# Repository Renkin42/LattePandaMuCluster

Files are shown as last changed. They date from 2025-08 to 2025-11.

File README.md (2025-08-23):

Latte Panda Mu Cluster Board
============================

This is a Mini-DTX cluster board for five Latte Panda Mu system-on-modules. Each slot recieves two sata connections, an m.2 M-key slot at pcie gen3x2 and a 2.5gb ethernet 
connection via an RTL8125B. Slot 1 has two USB-3 connections broken out to the rear IO along with HDMI and a single USB Type C port on a front panel header. Slots 2 and 3 
Each have a Front USB-3 connection, a rear USB-3 connection, and an M.2 E-key slot. Slots 4 and 5 have an open-back pcie gen 3x4 slot.

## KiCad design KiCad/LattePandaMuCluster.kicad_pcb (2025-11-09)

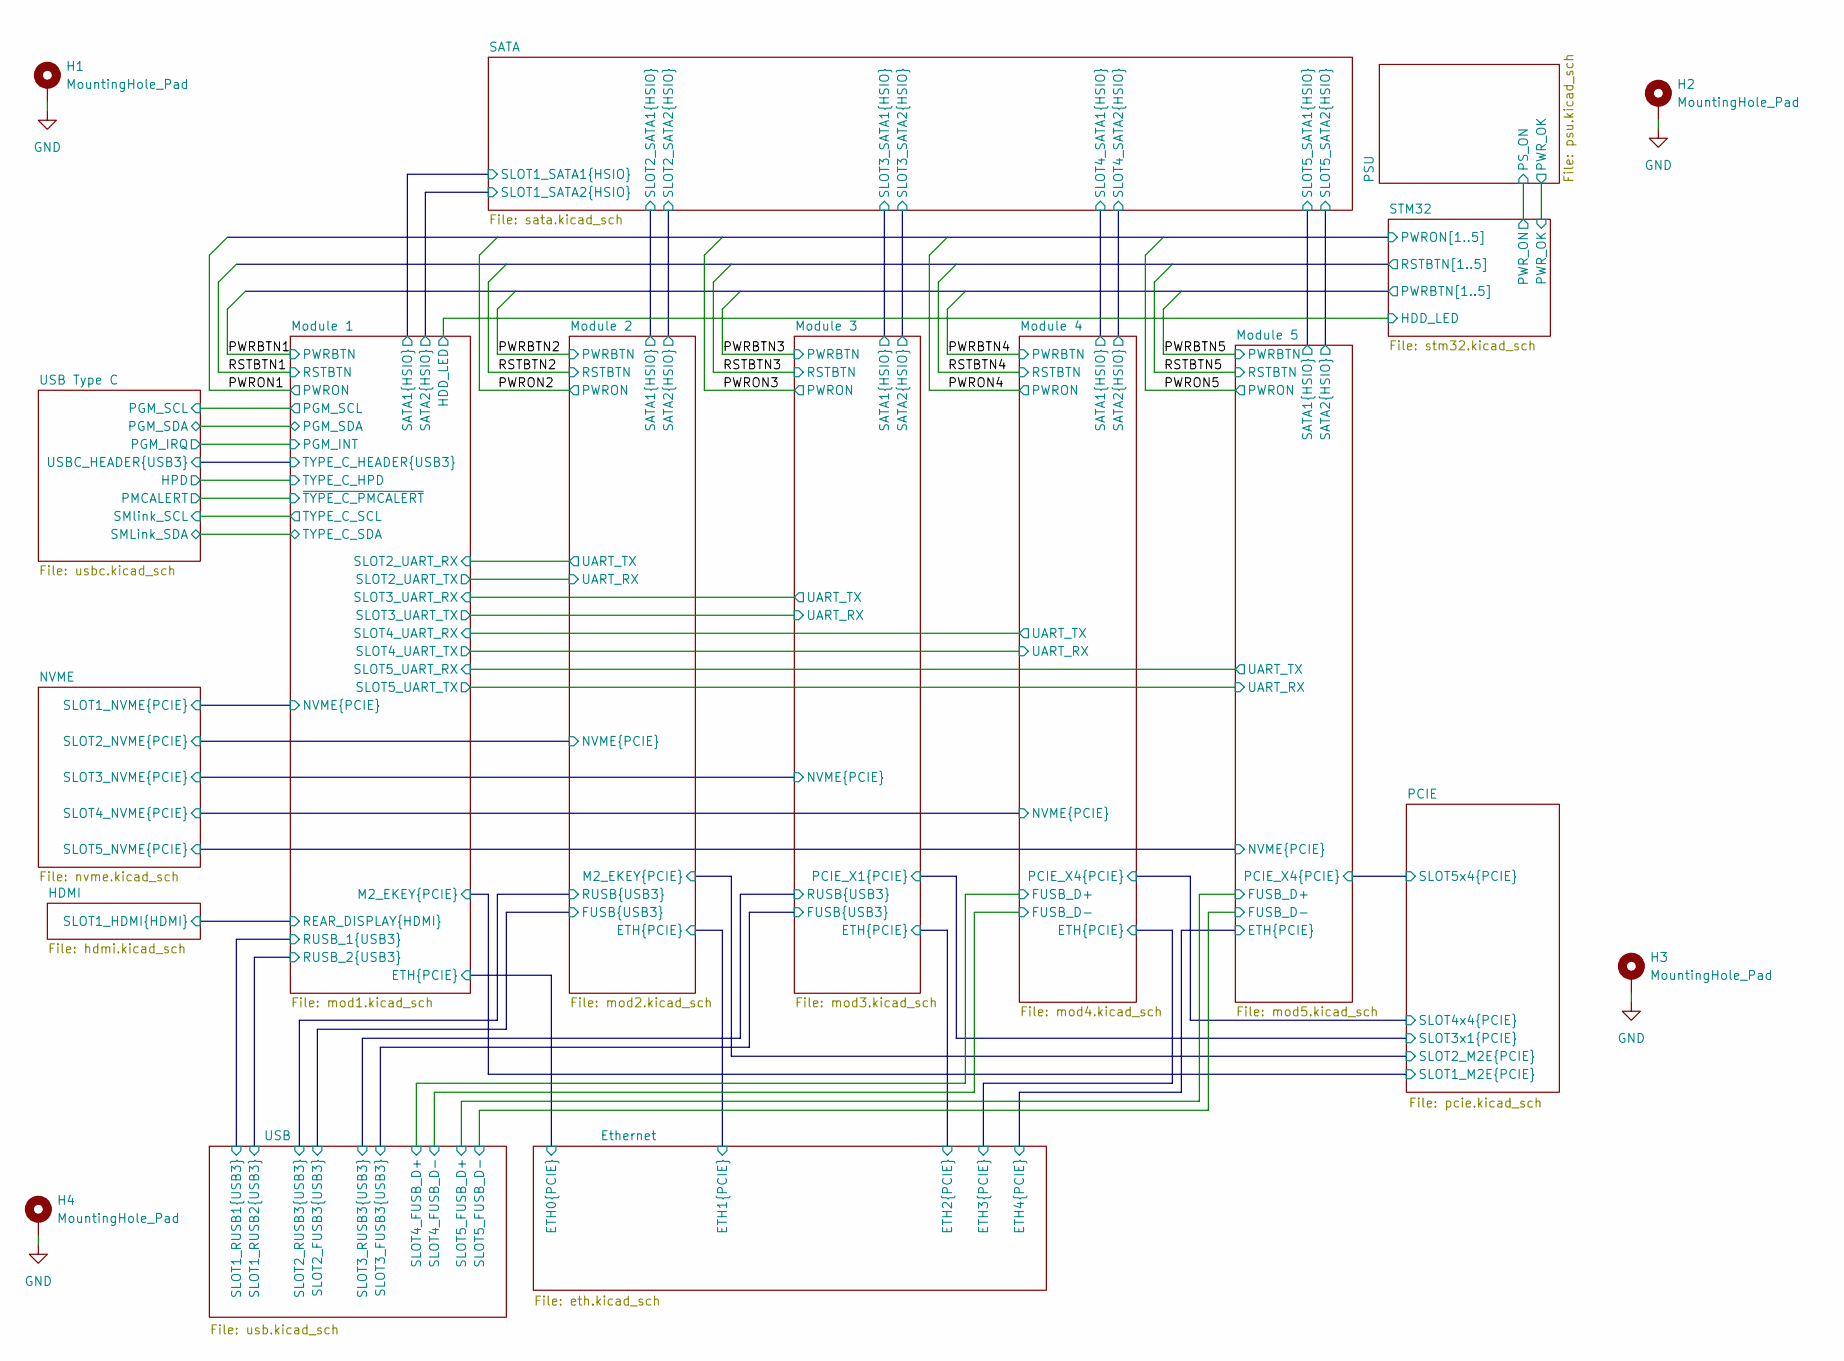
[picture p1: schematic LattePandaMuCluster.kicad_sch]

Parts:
H1, H2, H3, H4: MountingHole_Pad; MountingHole_4mm_Pad_Via

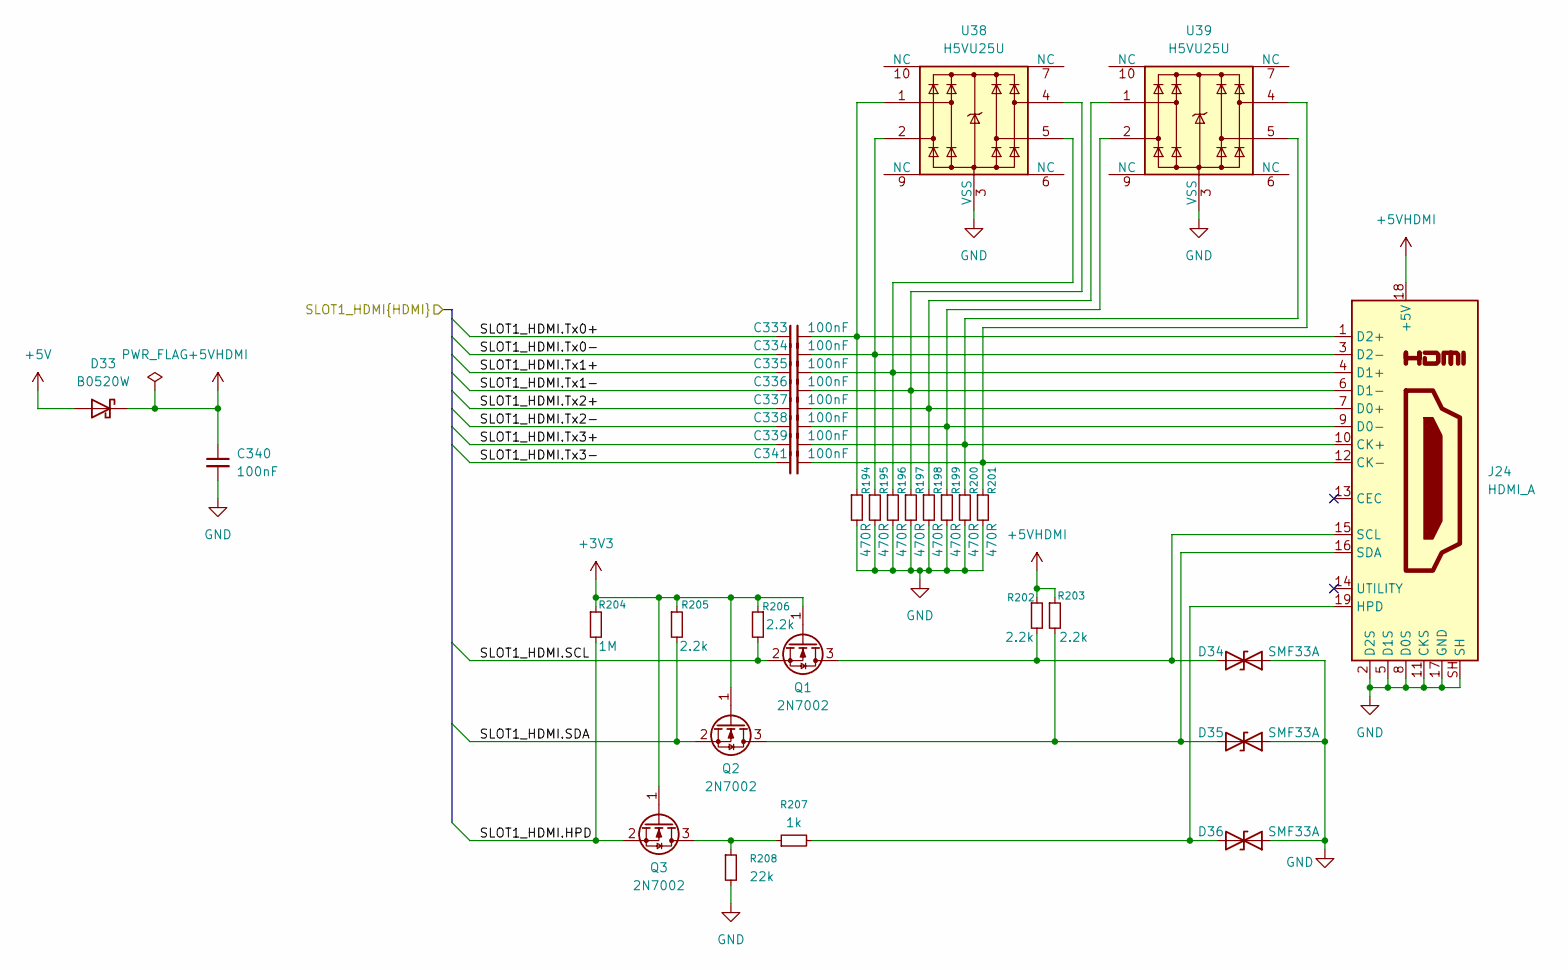
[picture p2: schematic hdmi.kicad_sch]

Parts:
C333, C334, C335, C336, C337, C338, C339, C340, C341: 100nF; C_0402_1005Metric
D33: B0520W; D_SOD-123
D34, D35, D36: SMF33A; D_SOD-123F
J24: HDMI_A; HDMI_A_Molex_208658-1001_Horizontal
Q1, Q2, Q3: 2N7002; SOT-23
R194, R195, R196, R197, R198, R199, R200, R201: 470R; R_0402_1005Metric
R202, R203, R205, R206: 2.2k; R_0402_1005Metric
R204: 1M; R_0402_1005Metric
R207: 1k; R_0805_2012Metric
R208: 22k; R_0402_1005Metric
U38, U39: H5VU25U; Diodes_UDFN-10_1.0x2.5mm_P0.5mm

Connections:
+3V3: Q1.1 (G), Q2.1 (G), Q3.1 (G), R204.1, R205.1, R206.1; also elsewhere on the board
+5V: D33.2 (A); also elsewhere on the board
+5VHDMI: C340.1, D33.1 (K), J24.18 (+5V), R202.1, R203.1
/HDMI/SLOT1_HDMI.HPD: Q3.2 (S), R204.2; also elsewhere on the board
/HDMI/SLOT1_HDMI.SCL: Q1.2 (S), R206.2; also elsewhere on the board
/HDMI/SLOT1_HDMI.SDA: Q2.2 (S), R205.2; also elsewhere on the board
/HDMI/SLOT1_HDMI.Tx0+: C333.1; also elsewhere on the board
/HDMI/SLOT1_HDMI.Tx0-: C334.1; also elsewhere on the board
/HDMI/SLOT1_HDMI.Tx1+: C335.1; also elsewhere on the board
/HDMI/SLOT1_HDMI.Tx1-: C336.1; also elsewhere on the board
/HDMI/SLOT1_HDMI.Tx2+: C337.1; also elsewhere on the board
/HDMI/SLOT1_HDMI.Tx2-: C338.1; also elsewhere on the board
/HDMI/SLOT1_HDMI.Tx3+: C339.1; also elsewhere on the board
/HDMI/SLOT1_HDMI.Tx3-: C341.1; also elsewhere on the board
unnamed: D34.2 (A2), J24.15 (SCL), Q1.3 (D), R202.2
unnamed: D35.2 (A2), J24.16 (SDA), Q2.3 (D), R203.2
unnamed: D36.2 (A2), J24.19 (HPD), R207.2
unnamed: C339.2, J24.10 (CK+), R200.1, U39.5
unnamed: C341.2, J24.12 (CK-), R201.1, U39.4
unnamed: C337.2, J24.7 (D0+), R198.1, U39.1
unnamed: C338.2, J24.9 (D0-), R199.1, U39.2
unnamed: C335.2, J24.4 (D1+), R196.1, U38.5
unnamed: C336.2, J24.6 (D1-), R197.1, U38.4
unnamed: C333.2, J24.1 (D2+), R194.1, U38.1
unnamed: C334.2, J24.3 (D2-), R195.1, U38.2
unnamed: Q3.3 (D), R207.1, R208.1

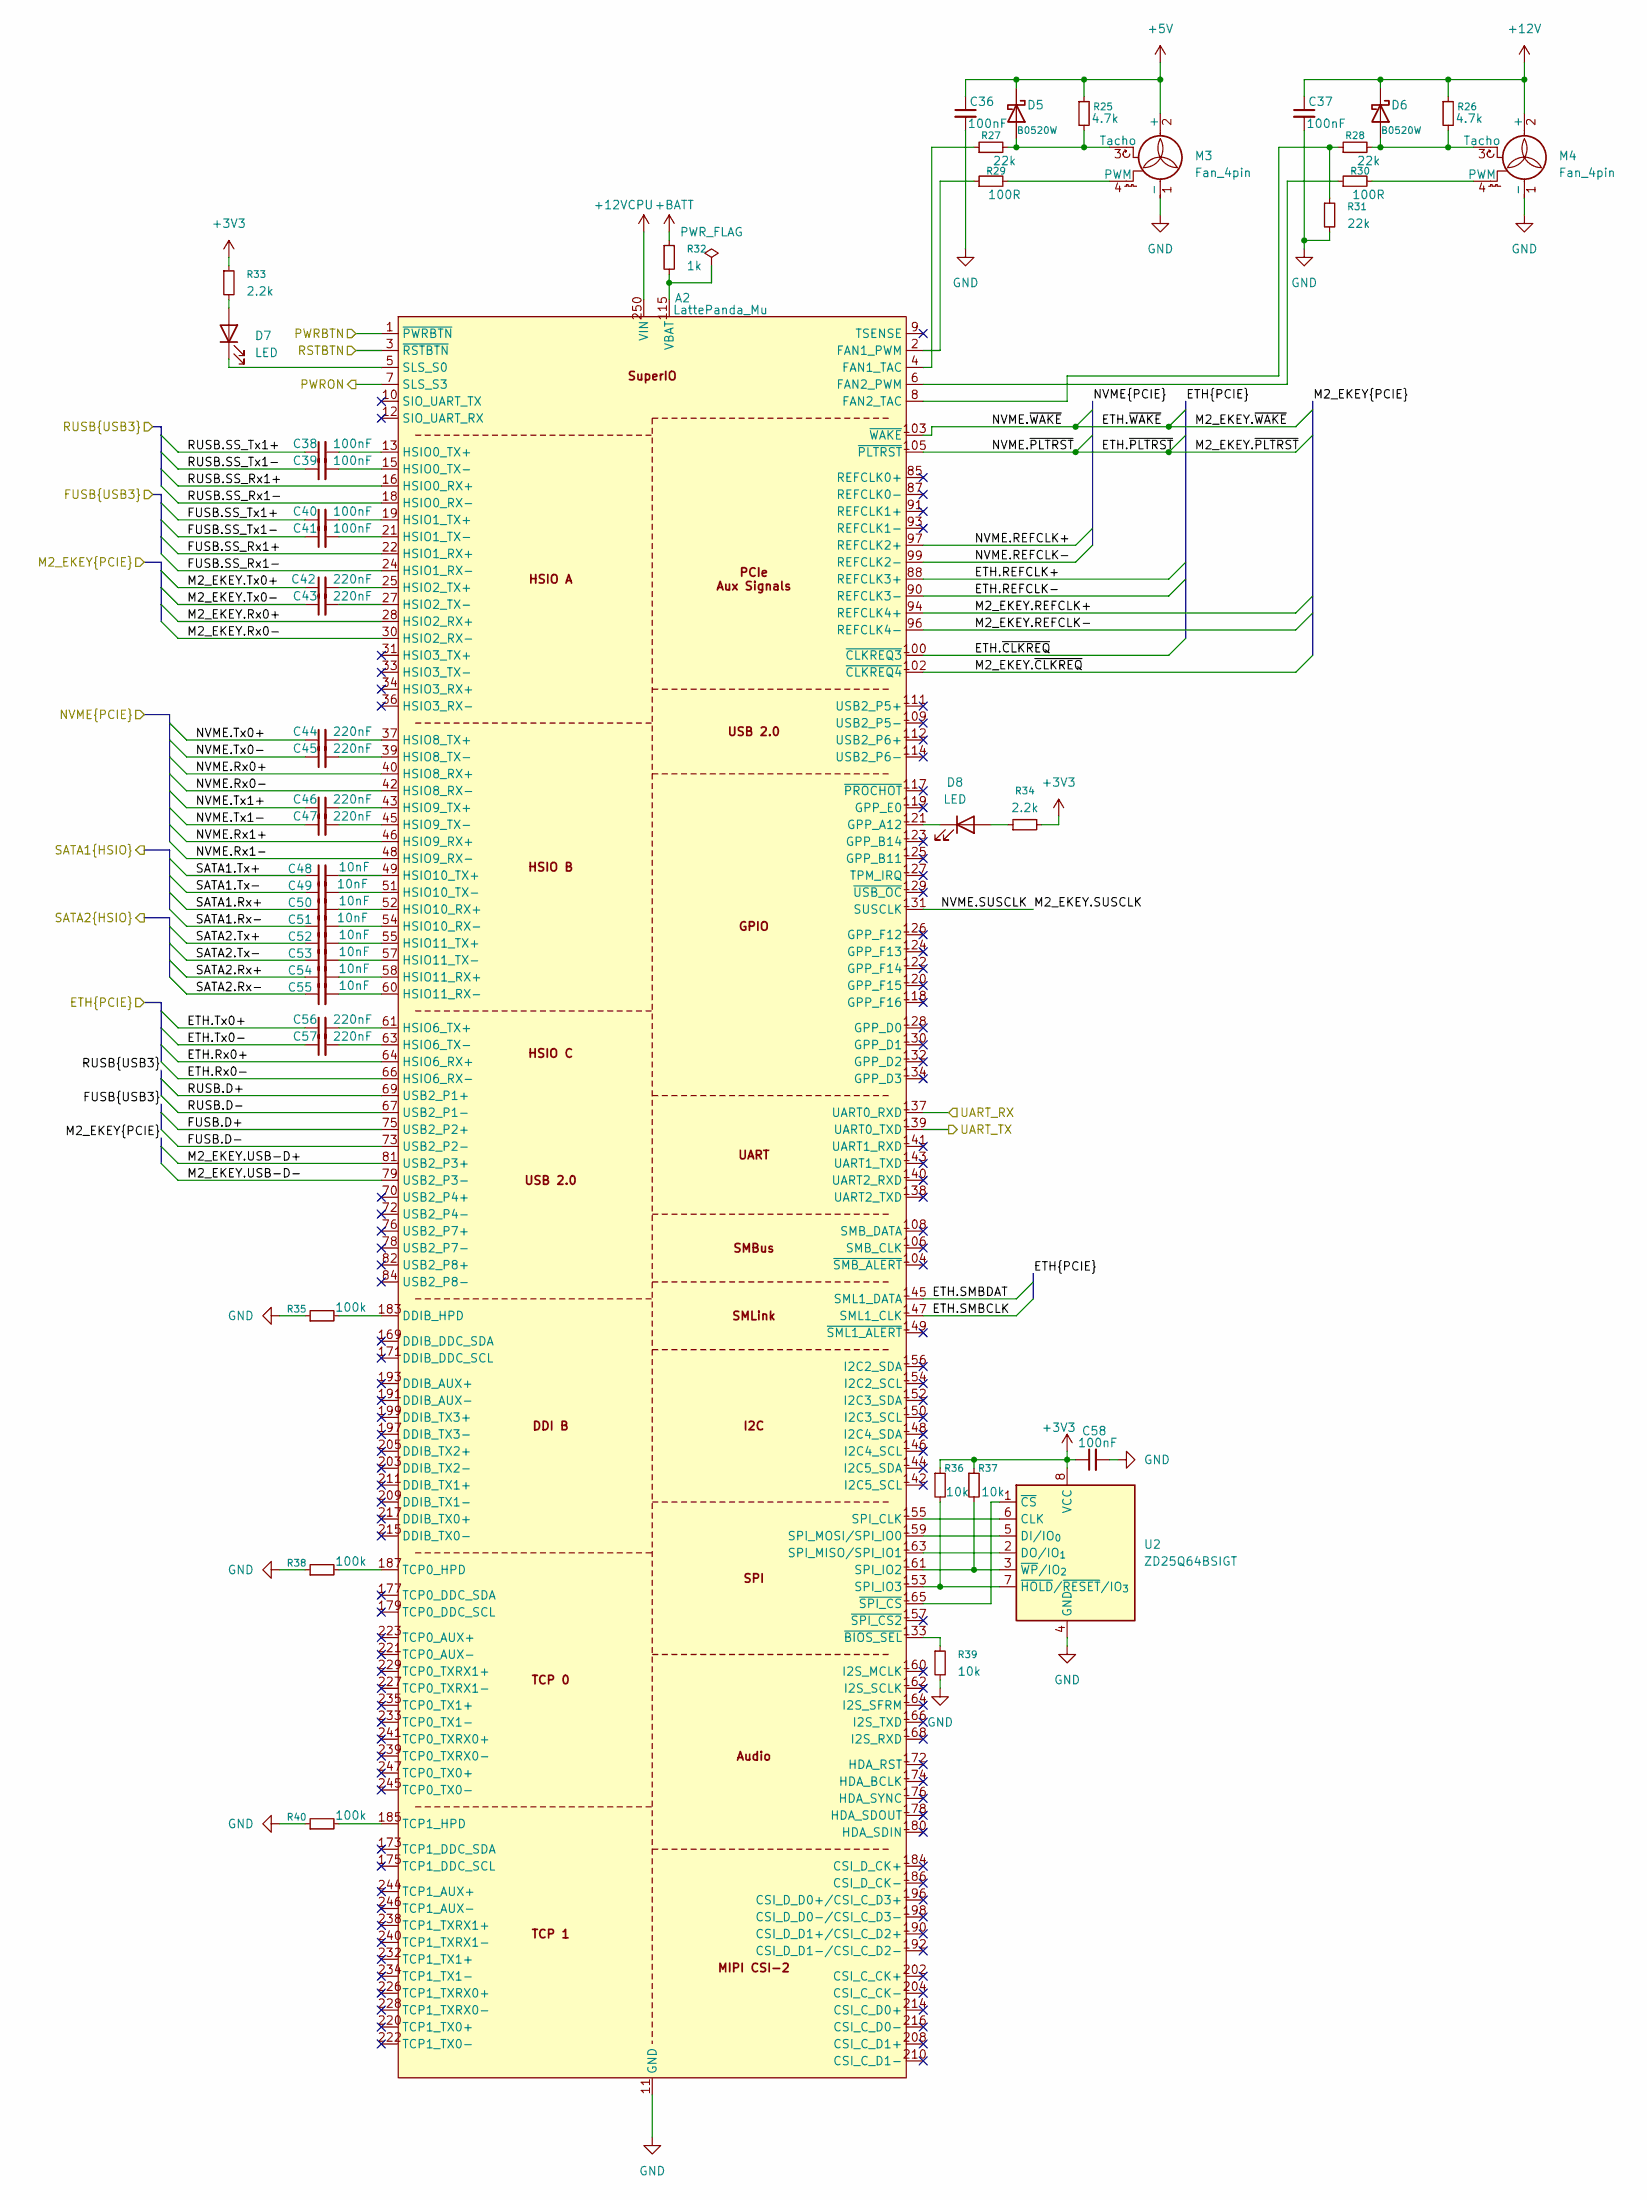
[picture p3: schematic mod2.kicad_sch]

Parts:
A2: LattePanda_Mu; ATTEND_124B-150A02
C36, C37, C38, C39, C40, C41, C58: 100nF; C_0402_1005Metric
C42, C43, C44, C45, C46, C47, C56, C57: 220nF; C_0402_1005Metric
C48, C49, C50, C51, C52, C53, C54, C55: 10nF; C_0402_1005Metric
D5, D6: B0520W; D_SOD-123
D7, D8: LED; LED_0603_1608Metric
M3: Fan_4pin; JST_PH_B4B-PH-K_1x04_P2.00mm_Vertical
M4: Fan_4pin; FanPinHeader_1x04_P2.54mm_Vertical
R25, R26: 4.7k; R_0402_1005Metric
R27, R28, R31: 22k; R_0402_1005Metric
R29, R30: 100R; R_0402_1005Metric
R32: 1k; R_0805_2012Metric
R33, R34: 2.2k; R_0402_1005Metric
R35, R38, R40: 100k; R_0402_1005Metric
R36, R37, R39: 10k; R_0402_1005Metric
U2: ZD25Q64BSIGT; SOIC-8_5.3x5.3mm_P1.27mm

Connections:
+3V3: C58.1, R33.1, R34.2, R36.1, R37.1, U2.8 (VCC); also elsewhere on the board
+5V: C36.1, D5.1 (K), M3.2 (+), R25.1; also elsewhere on the board
+12V: C37.1, D6.1 (K), M4.2 (+), R26.1; also elsewhere on the board
+12VCPU: A2.250 (VIN), A2.251 (VIN), A2.252 (VIN), A2.253 (VIN), A2.254 (VIN), A2.255 (VIN), A2.256 (VIN), A2.257 (VIN), A2.258 (VIN), A2.259 (VIN), A2.260 (VIN); also elsewhere on the board
+BATT: R32.1; also elsewhere on the board
/Module 1/SLOT2_UART_RX: A2.139 (UART0_TXD); also elsewhere on the board
/Module 1/SLOT2_UART_TX: A2.137 (UART0_RXD); also elsewhere on the board
/Module 2/ETH.REFCLK+: A2.88 (REFCLK3+); also elsewhere on the board
/Module 2/ETH.REFCLK-: A2.90 (REFCLK3-); also elsewhere on the board
/Module 2/ETH.Rx0+: A2.64 (HSIO6_RX+); also elsewhere on the board
/Module 2/ETH.Rx0-: A2.66 (HSIO6_RX-); also elsewhere on the board
/Module 2/ETH.SMBCLK: A2.147 (SML1_CLK); also elsewhere on the board
/Module 2/ETH.SMBDAT: A2.145 (SML1_DATA); also elsewhere on the board
/Module 2/ETH.Tx0+: C56.1; also elsewhere on the board
/Module 2/ETH.Tx0-: C57.1; also elsewhere on the board
/Module 2/ETH.~CLKREQ: A2.100 (~CLKREQ3); also elsewhere on the board
/Module 2/FUSB.D+: A2.75 (USB2_P2+); also elsewhere on the board
/Module 2/FUSB.D-: A2.73 (USB2_P2-); also elsewhere on the board
/Module 2/FUSB.SS_Rx1+: A2.22 (HSIO1_RX+); also elsewhere on the board
/Module 2/FUSB.SS_Rx1-: A2.24 (HSIO1_RX-); also elsewhere on the board
/Module 2/FUSB.SS_Tx1+: C40.1; also elsewhere on the board
/Module 2/FUSB.SS_Tx1-: C41.1; also elsewhere on the board
/Module 2/M2_EKEY.REFCLK+: A2.94 (REFCLK4+); also elsewhere on the board
/Module 2/M2_EKEY.REFCLK-: A2.96 (REFCLK4-); also elsewhere on the board
/Module 2/M2_EKEY.Rx0+: A2.28 (HSIO2_RX+); also elsewhere on the board
/Module 2/M2_EKEY.Rx0-: A2.30 (HSIO2_RX-); also elsewhere on the board
/Module 2/M2_EKEY.Tx0+: C42.1; also elsewhere on the board
/Module 2/M2_EKEY.Tx0-: C43.1; also elsewhere on the board
/Module 2/M2_EKEY.USB-D+: A2.81 (USB2_P3+); also elsewhere on the board
/Module 2/M2_EKEY.USB-D-: A2.79 (USB2_P3-); also elsewhere on the board
/Module 2/M2_EKEY.~CLKREQ: A2.102 (~CLKREQ4)
/Module 2/NVME.REFCLK+: A2.97 (REFCLK2+); also elsewhere on the board
/Module 2/NVME.REFCLK-: A2.99 (REFCLK2-); also elsewhere on the board
/Module 2/NVME.Rx0+: A2.40 (HSIO8_RX+); also elsewhere on the board
/Module 2/NVME.Rx0-: A2.42 (HSIO8_RX-); also elsewhere on the board
/Module 2/NVME.Rx1+: A2.46 (HSIO9_RX+); also elsewhere on the board
/Module 2/NVME.Rx1-: A2.48 (HSIO9_RX-); also elsewhere on the board
/Module 2/NVME.SUSCLK: A2.131 (SUSCLK); also elsewhere on the board
/Module 2/NVME.Tx0+: C44.1; also elsewhere on the board
/Module 2/NVME.Tx0-: C45.1; also elsewhere on the board
/Module 2/NVME.Tx1+: C46.1; also elsewhere on the board
/Module 2/NVME.Tx1-: C47.1; also elsewhere on the board
/Module 2/NVME.~PLTRST: A2.105 (~PLTRST); also elsewhere on the board
/Module 2/NVME.~WAKE: A2.103 (~WAKE); also elsewhere on the board
/Module 2/RUSB.D+: A2.69 (USB2_P1+); also elsewhere on the board
/Module 2/RUSB.D-: A2.67 (USB2_P1-); also elsewhere on the board
/Module 2/RUSB.SS_Rx1+: A2.16 (HSIO0_RX+); also elsewhere on the board
/Module 2/RUSB.SS_Rx1-: A2.18 (HSIO0_RX-); also elsewhere on the board
/Module 2/RUSB.SS_Tx1+: C38.1; also elsewhere on the board
/Module 2/RUSB.SS_Tx1-: C39.1; also elsewhere on the board
/Module 2/SATA1.Rx+: C50.1; also elsewhere on the board
/Module 2/SATA1.Rx-: C51.1; also elsewhere on the board
/Module 2/SATA1.Tx+: C48.1; also elsewhere on the board
/Module 2/SATA1.Tx-: C49.1; also elsewhere on the board
/Module 2/SATA2.Rx+: C54.1; also elsewhere on the board
/Module 2/SATA2.Rx-: C55.1; also elsewhere on the board
/Module 2/SATA2.Tx+: C52.1; also elsewhere on the board
/Module 2/SATA2.Tx-: C53.1; also elsewhere on the board
/STM32/PWRBTN2: A2.1 (~PWRBTN); also elsewhere on the board
/STM32/PWRON2: A2.7 (SLS_S3); also elsewhere on the board
/STM32/RSTBTN2: A2.3 (~RSTBTN); also elsewhere on the board
unnamed: A2.183 (DDIB_HPD), R35.2
unnamed: A2.2 (FAN1_PWM), R29.1
unnamed: A2.4 (FAN1_TAC), R27.1
unnamed: A2.6 (FAN2_PWM), R30.1
unnamed: A2.8 (FAN2_TAC), R28.1, R31.1
unnamed: A2.121 (GPP_A12), D8.1 (K)
unnamed: A2.13 (HSIO0_TX+), C38.2
unnamed: A2.15 (HSIO0_TX-), C39.2
unnamed: A2.19 (HSIO1_TX+), C40.2
unnamed: A2.21 (HSIO1_TX-), C41.2
unnamed: A2.25 (HSIO2_TX+), C42.2
unnamed: A2.27 (HSIO2_TX-), C43.2
unnamed: A2.61 (HSIO6_TX+), C56.2
unnamed: A2.63 (HSIO6_TX-), C57.2
unnamed: A2.37 (HSIO8_TX+), C44.2
unnamed: A2.39 (HSIO8_TX-), C45.2
unnamed: A2.43 (HSIO9_TX+), C46.2
unnamed: A2.45 (HSIO9_TX-), C47.2
unnamed: A2.52 (HSIO10_RX+), C50.2
unnamed: A2.54 (HSIO10_RX-), C51.2
unnamed: A2.49 (HSIO10_TX+), C48.2
unnamed: A2.51 (HSIO10_TX-), C49.2
unnamed: A2.58 (HSIO11_RX+), C54.2
unnamed: A2.60 (HSIO11_RX-), C55.2
unnamed: A2.55 (HSIO11_TX+), C52.2
unnamed: A2.57 (HSIO11_TX-), C53.2
unnamed: A2.5 (SLS_S0), D7.1 (K)
unnamed: A2.155 (SPI_CLK), U2.6 (CLK)
unnamed: A2.161 (SPI_IO2), R37.2, U2.3 (~WP/IO_{2})
unnamed: A2.153 (SPI_IO3), R36.2, U2.7 (~HOLD/~RESET/IO_{3})
unnamed: A2.163 (SPI_MISO/SPI_IO1), U2.2 (DO/IO_{1})
unnamed: A2.159 (SPI_MOSI/SPI_IO0), U2.5 (DI/IO_{0})
unnamed: A2.187 (TCP0_HPD), R38.2
unnamed: A2.185 (TCP1_HPD), R40.2
unnamed: A2.115 (VBAT), R32.2
unnamed: A2.133 (~BIOS_SEL), R39.1
unnamed: A2.165 (~SPI_CS), U2.1 (~CS)
unnamed: D5.2 (A), M3.3 (Tacho), R25.2, R27.2
unnamed: D6.2 (A), M4.3 (Tacho), R26.2, R28.2
unnamed: D7.2 (A), R33.2
unnamed: D8.2 (A), R34.1
unnamed: M3.4 (PWM), R29.2
unnamed: M4.4 (PWM), R30.2

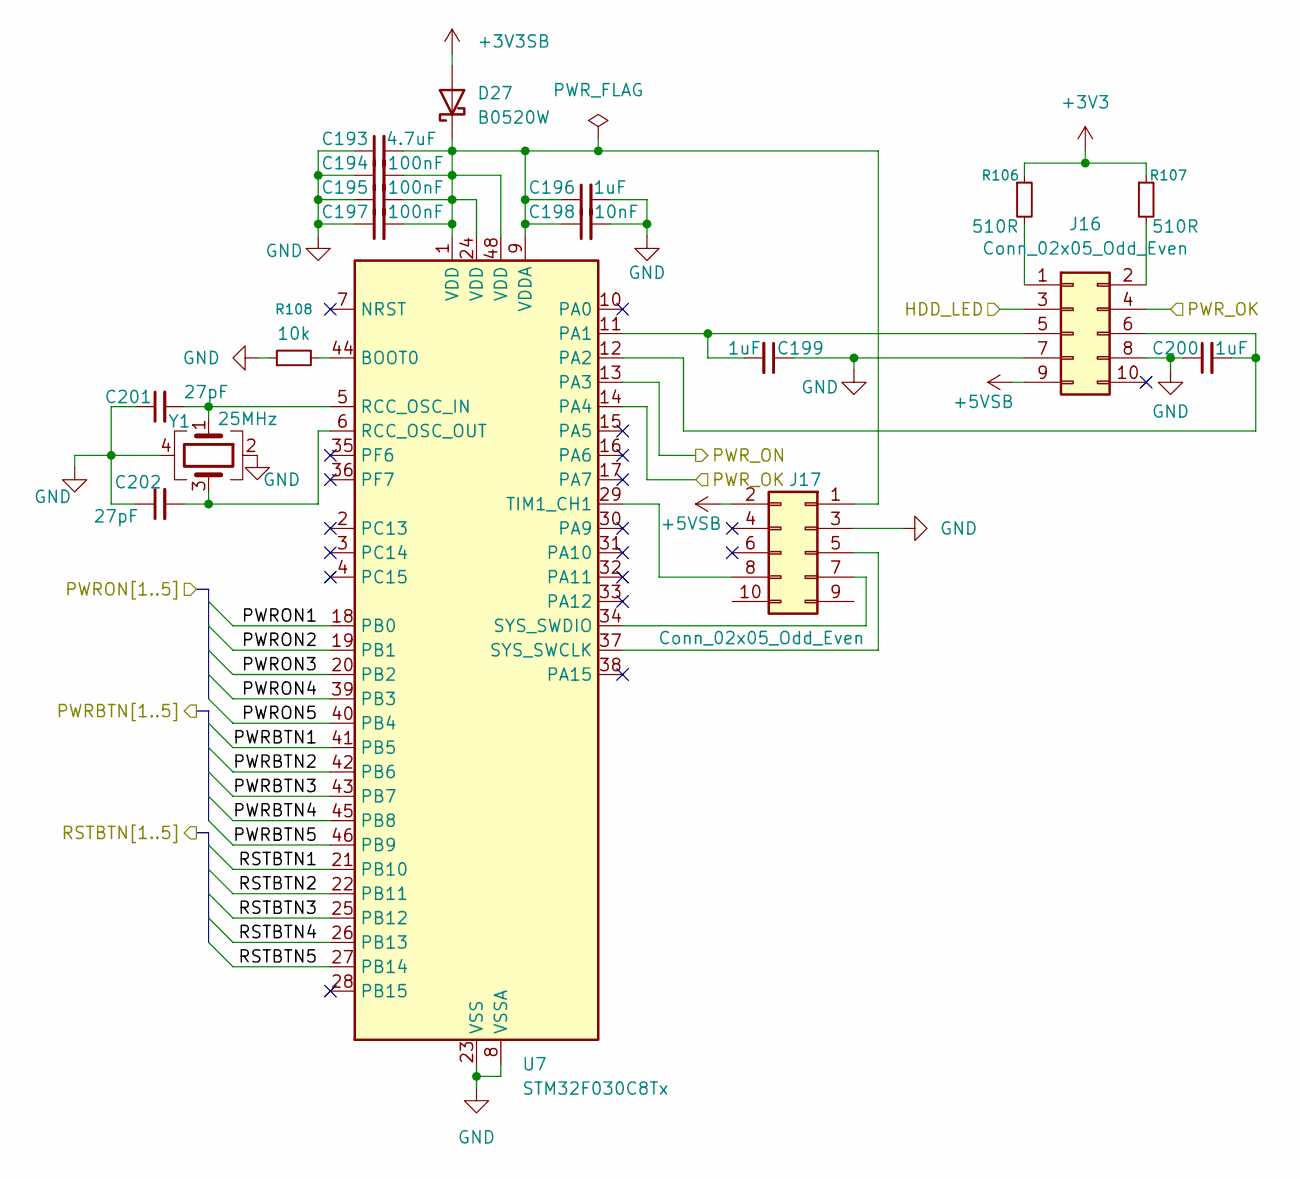
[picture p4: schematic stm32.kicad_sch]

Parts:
C193: 4.7uF; C_0402_1005Metric
C194, C195, C197: 100nF; C_0402_1005Metric
C196, C199, C200: 1uF; C_0402_1005Metric
C198: 10nF; C_0402_1005Metric
C201, C202: 27pF; C_0402_1005Metric
D27: B0520W; D_SOD-123
J16, J17: Conn_02x05_Odd_Even; PinHeader_2x05_P2.54mm_Vertical
R106, R107: 510R; R_0402_1005Metric
R108: 10k; R_0402_1005Metric
U7: STM32F030C8Tx; LQFP-48_7x7mm_P0.5mm
Y1: 25MHz; Crystal_SMD_3225-4Pin_3.2x2.5mm

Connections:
+3V3: R106.1, R107.1; also elsewhere on the board
+3V3SB: D27.2 (A); also elsewhere on the board
+5VSB: J16.9, J17.2; also elsewhere on the board
/Module 1/HDD_LED: J16.3; also elsewhere on the board
/PSU/PS_ON: U7.13 (PA3); also elsewhere on the board
/PSU/PWR_OK: J16.4, U7.14 (PA4); also elsewhere on the board
/STM32/PWRBTN1: U7.41 (PB5); also elsewhere on the board
/STM32/PWRBTN2: U7.42 (PB6); also elsewhere on the board
/STM32/PWRBTN3: U7.43 (PB7); also elsewhere on the board
/STM32/PWRBTN4: U7.45 (PB8); also elsewhere on the board
/STM32/PWRBTN5: U7.46 (PB9); also elsewhere on the board
/STM32/PWRON1: U7.18 (PB0); also elsewhere on the board
/STM32/PWRON2: U7.19 (PB1); also elsewhere on the board
/STM32/PWRON3: U7.20 (PB2); also elsewhere on the board
/STM32/PWRON4: U7.39 (PB3); also elsewhere on the board
/STM32/PWRON5: U7.40 (PB4); also elsewhere on the board
/STM32/RSTBTN1: U7.21 (PB10); also elsewhere on the board
/STM32/RSTBTN2: U7.22 (PB11); also elsewhere on the board
/STM32/RSTBTN3: U7.25 (PB12); also elsewhere on the board
/STM32/RSTBTN4: U7.26 (PB13); also elsewhere on the board
/STM32/RSTBTN5: U7.27 (PB14); also elsewhere on the board
unnamed: C193.2, C194.2, C195.2, C196.1, C197.2, C198.1, D27.1 (K), J17.1, U7.1 (VDD), U7.9 (VDDA), U7.24 (VDD), U7.48 (VDD)
unnamed: J16.1, R106.2
unnamed: J16.2, R107.2
unnamed: C199.2, J16.5, U7.11 (PA1)
unnamed: C200.2, J16.6, U7.12 (PA2)
unnamed: J17.5, U7.37 (SYS_SWCLK)
unnamed: J17.7, U7.34 (SYS_SWDIO)
unnamed: J17.8, U7.29 (TIM1_CH1)
unnamed: R108.2, U7.44 (BOOT0)
unnamed: C201.2, U7.5 (RCC_OSC_IN), Y1.1
unnamed: C202.2, U7.6 (RCC_OSC_OUT), Y1.3

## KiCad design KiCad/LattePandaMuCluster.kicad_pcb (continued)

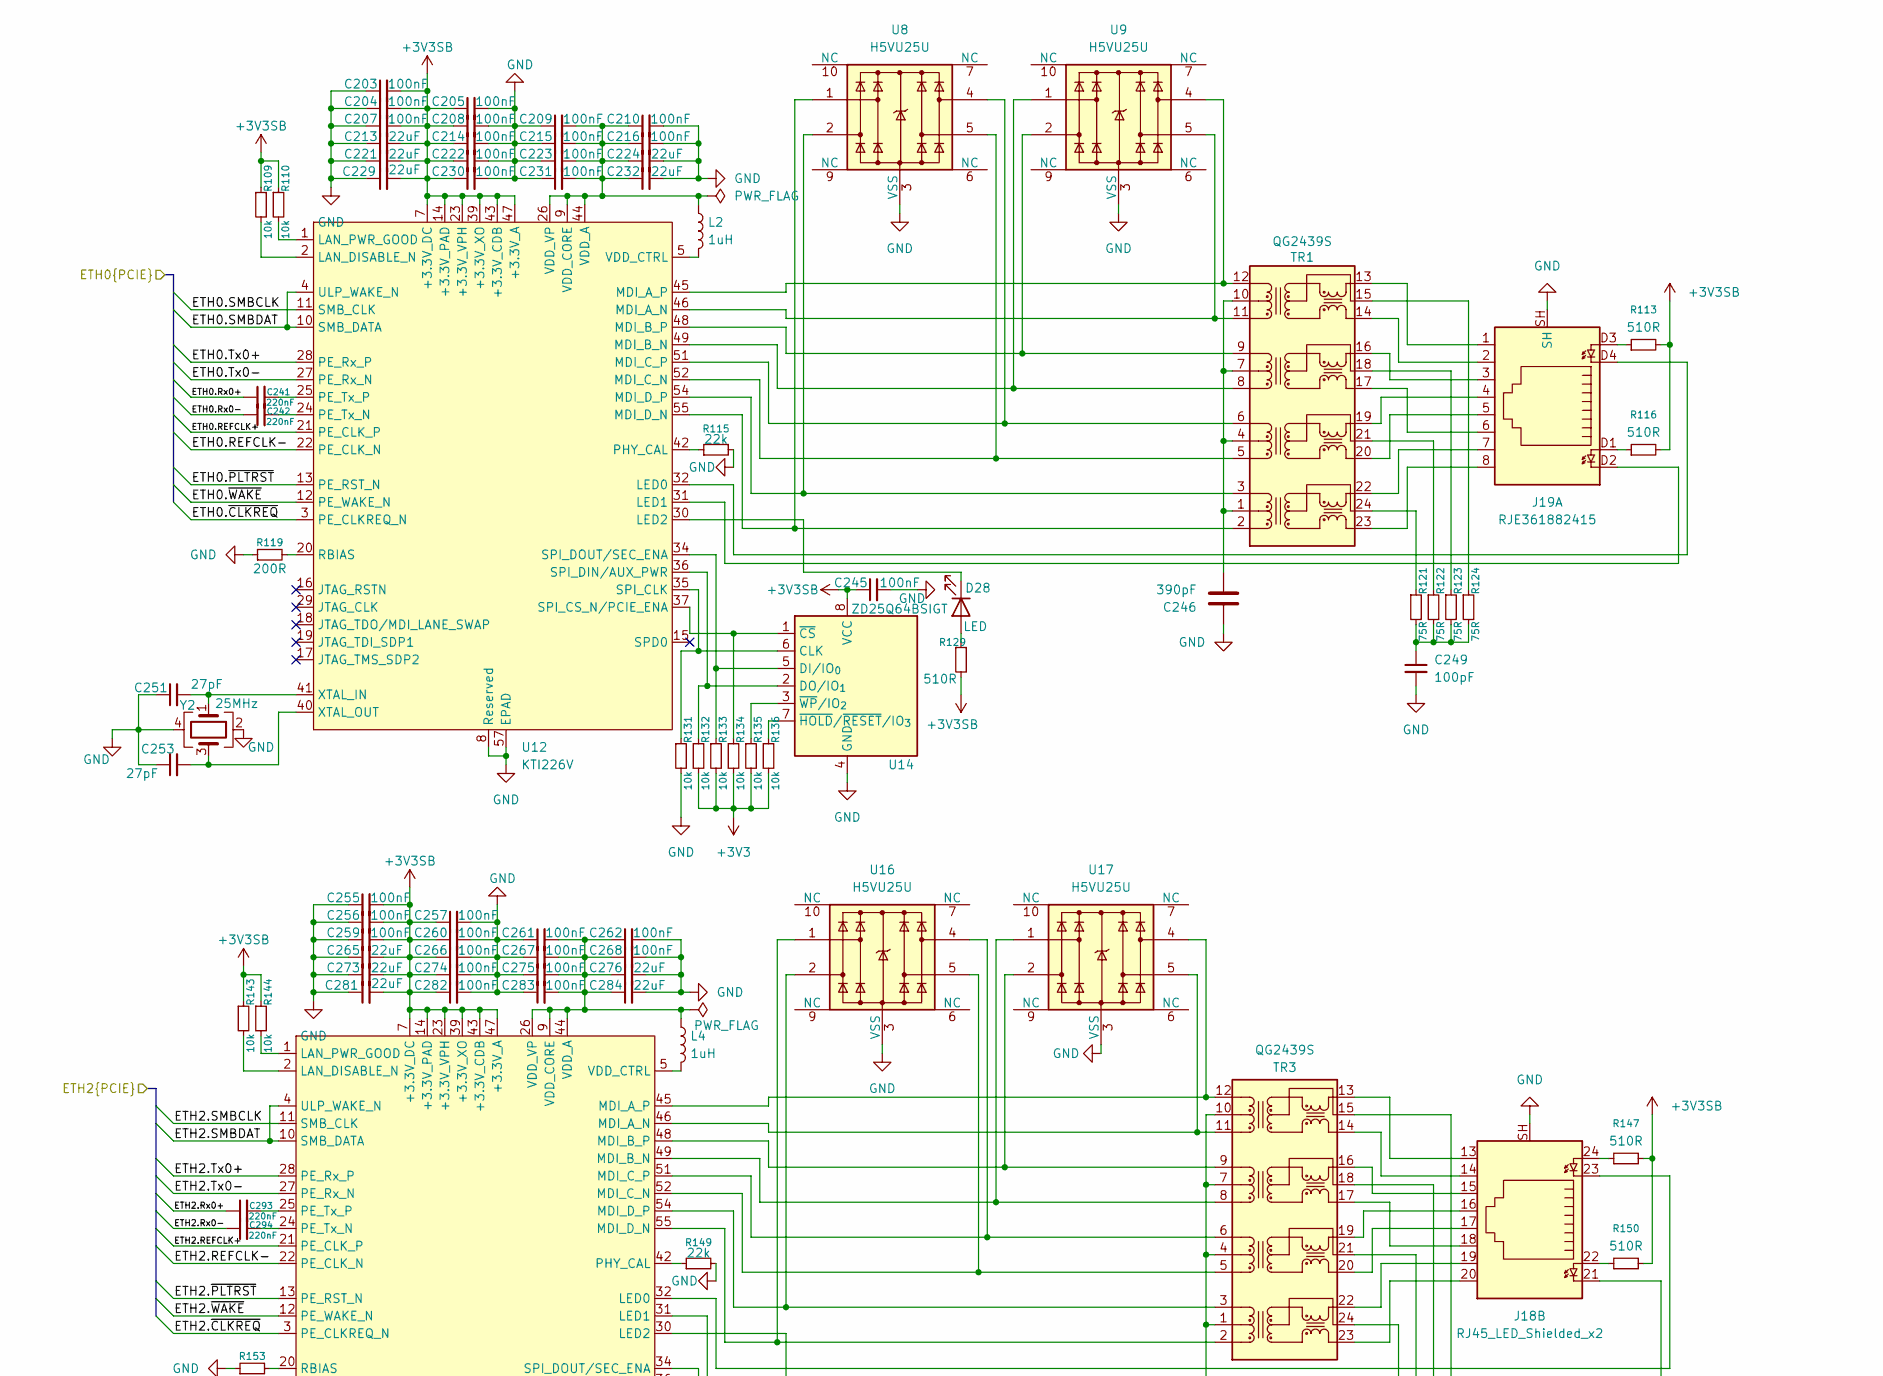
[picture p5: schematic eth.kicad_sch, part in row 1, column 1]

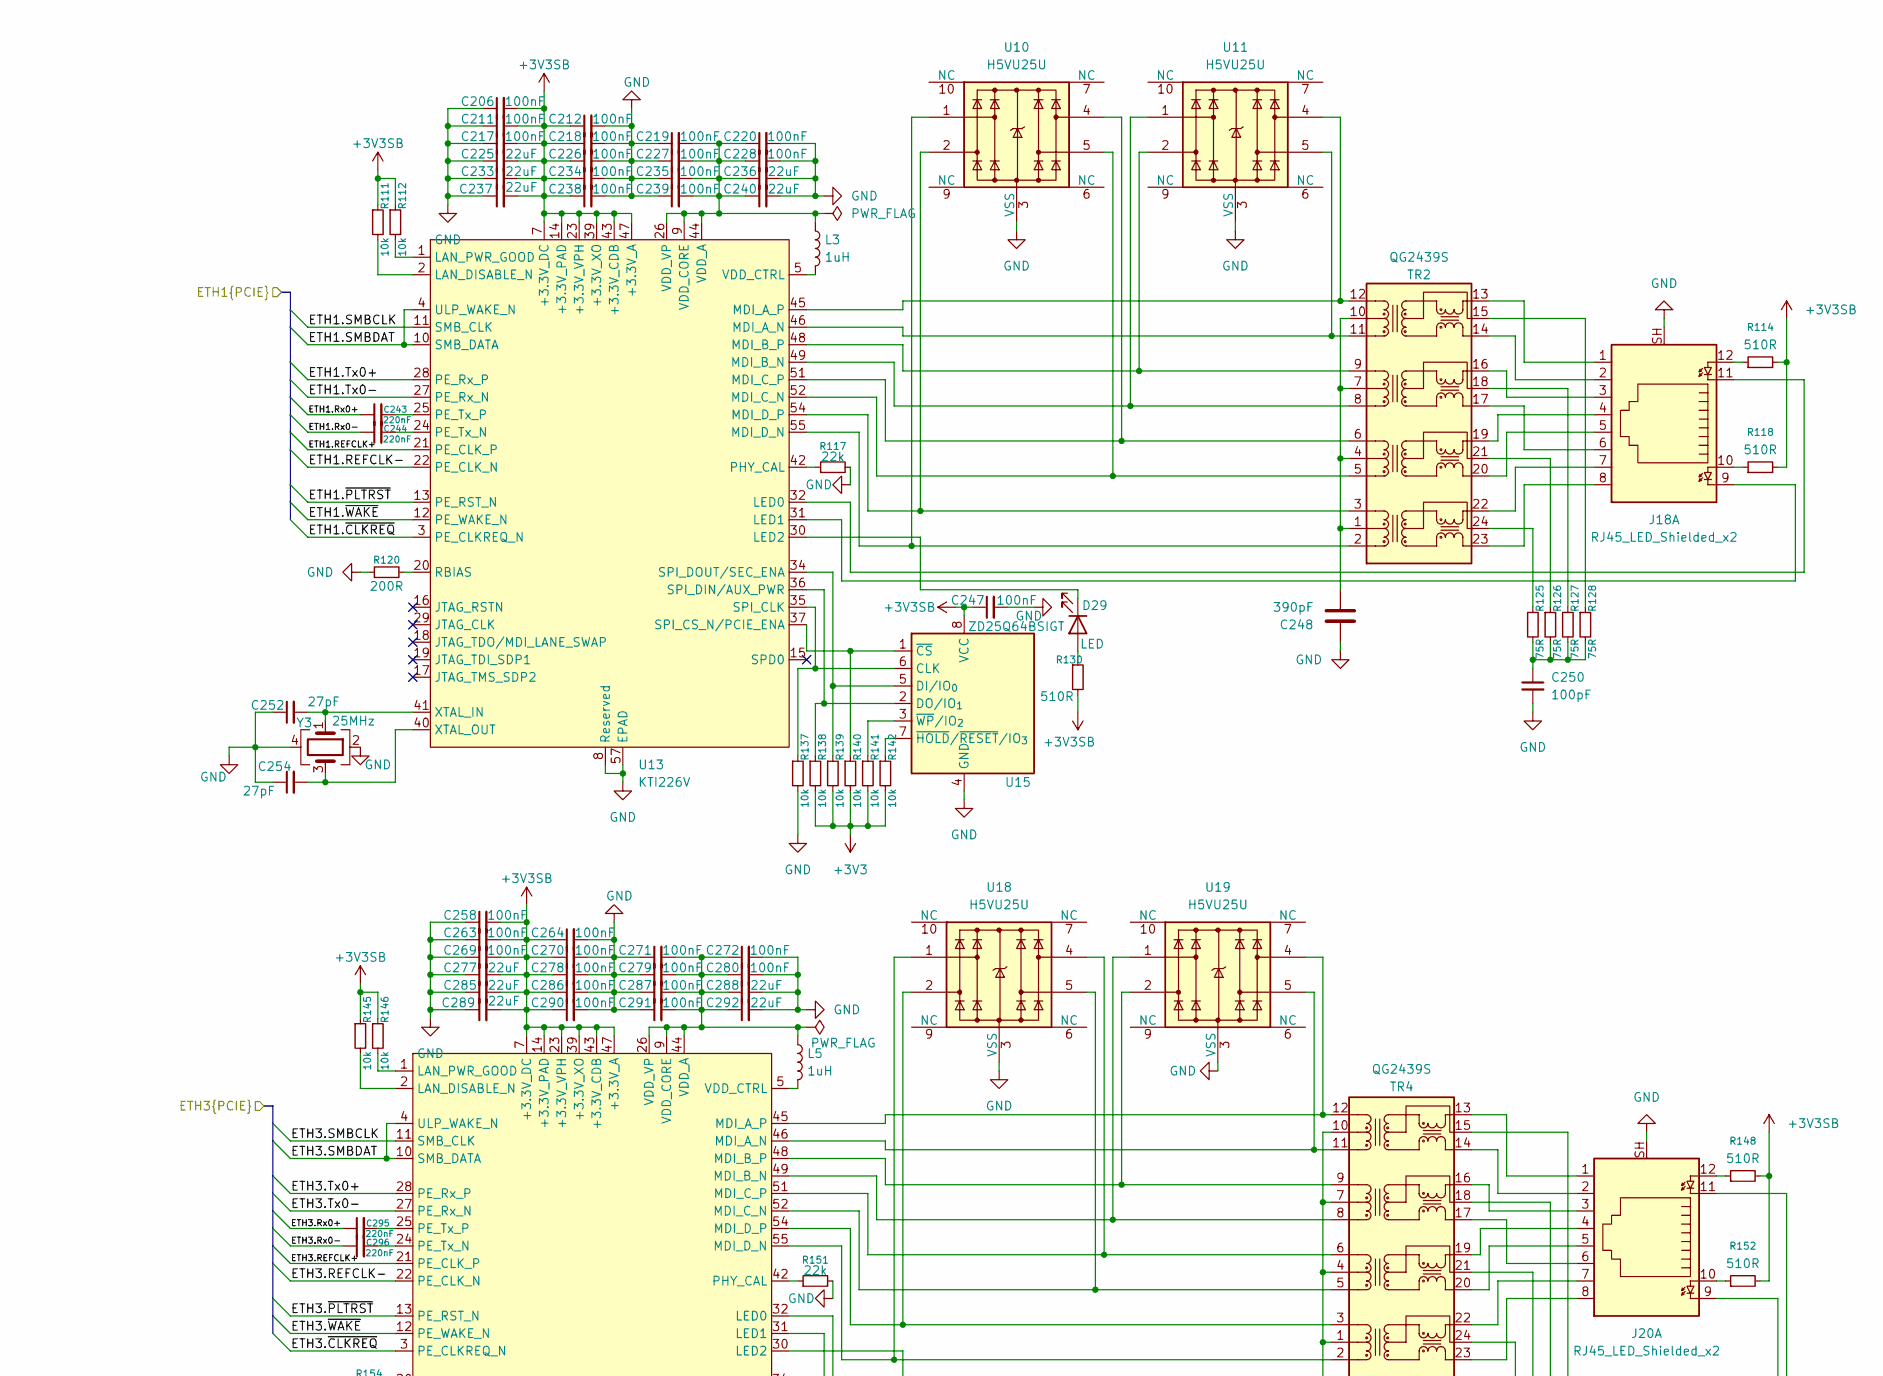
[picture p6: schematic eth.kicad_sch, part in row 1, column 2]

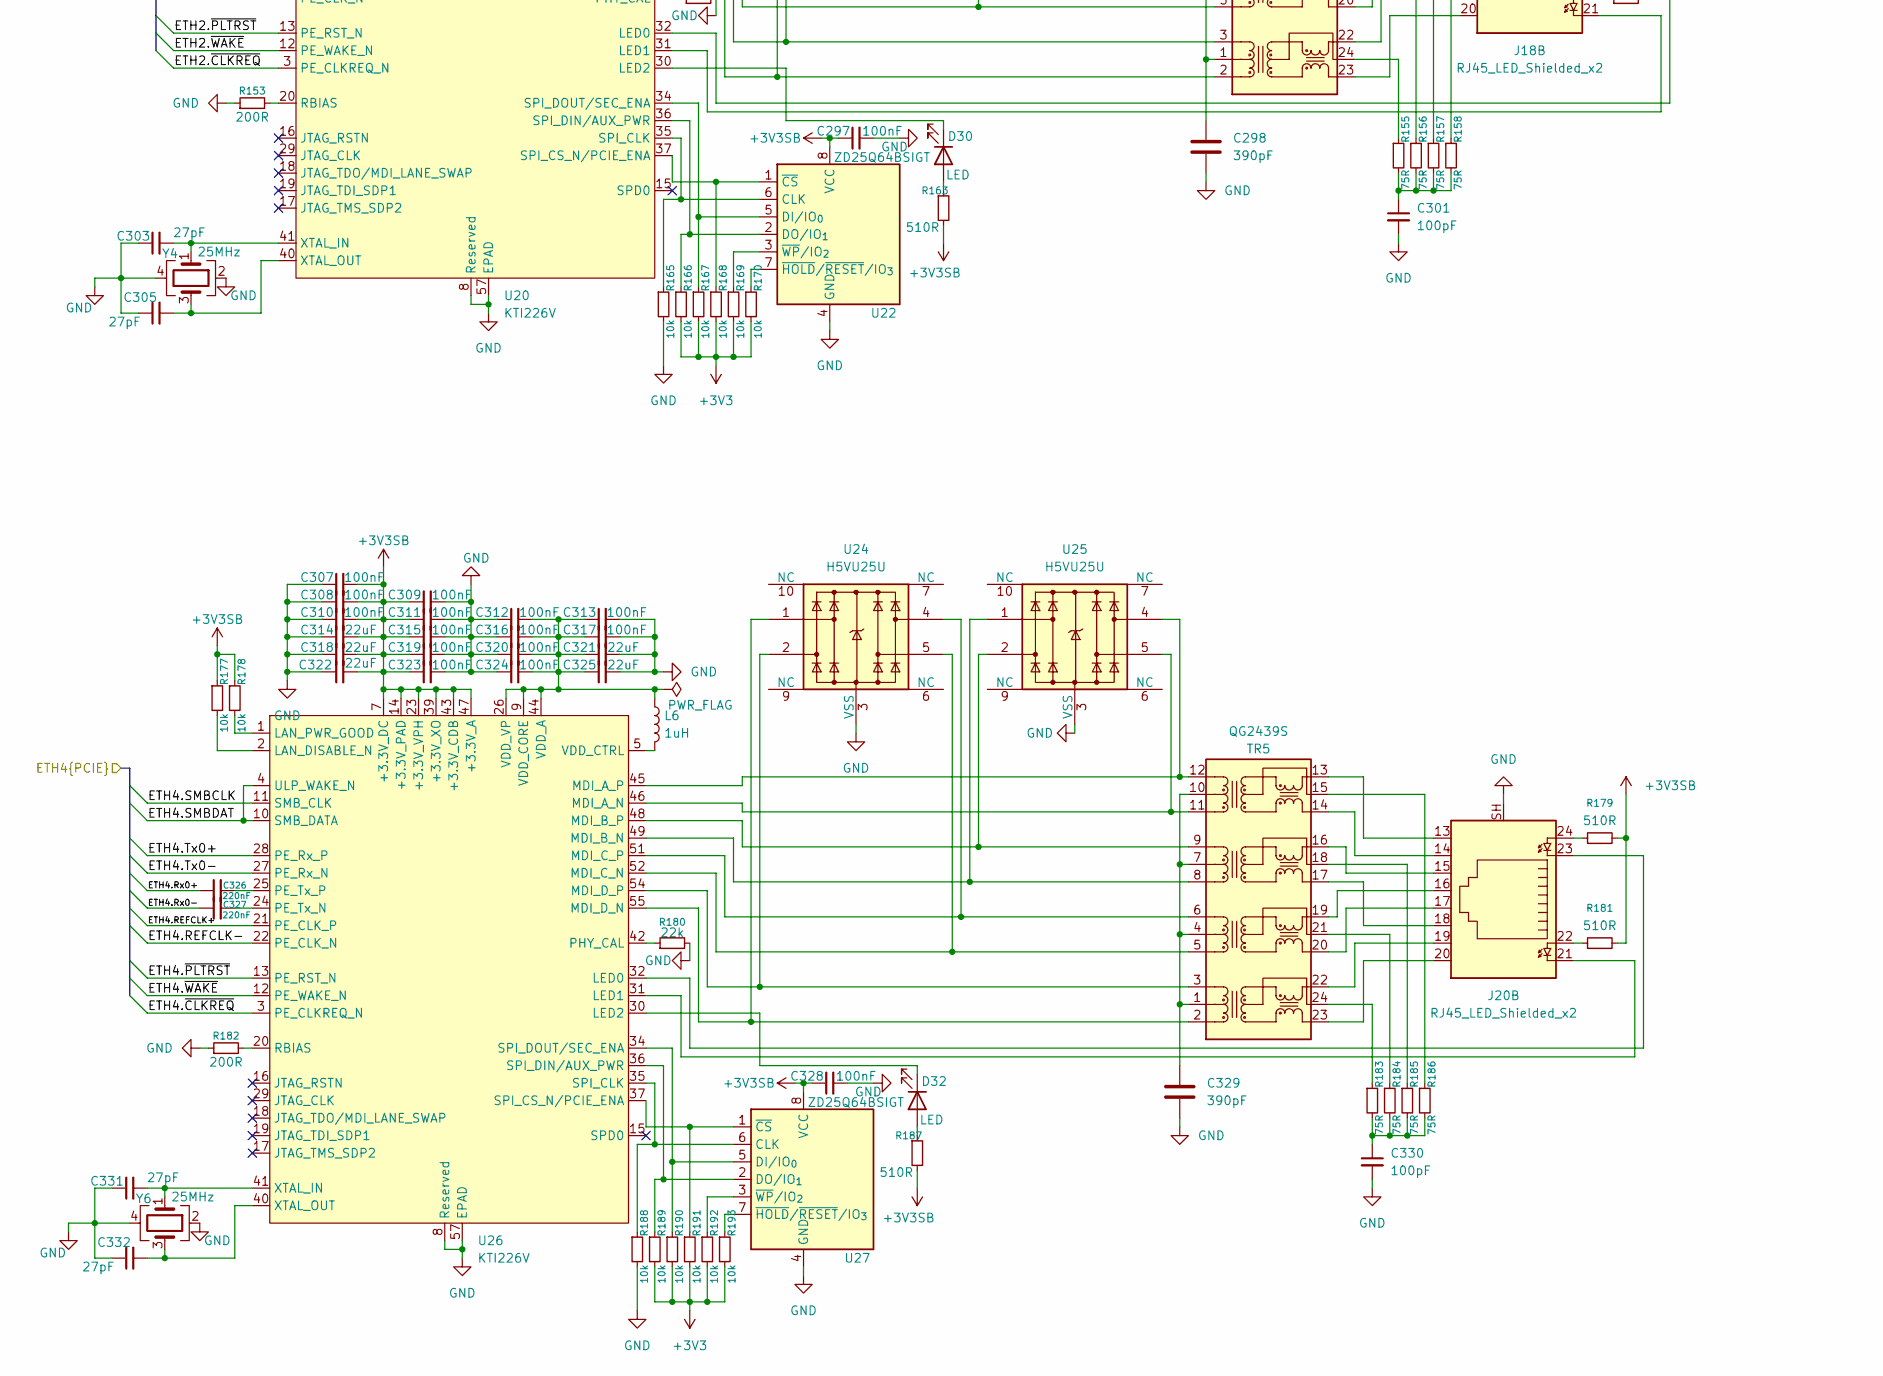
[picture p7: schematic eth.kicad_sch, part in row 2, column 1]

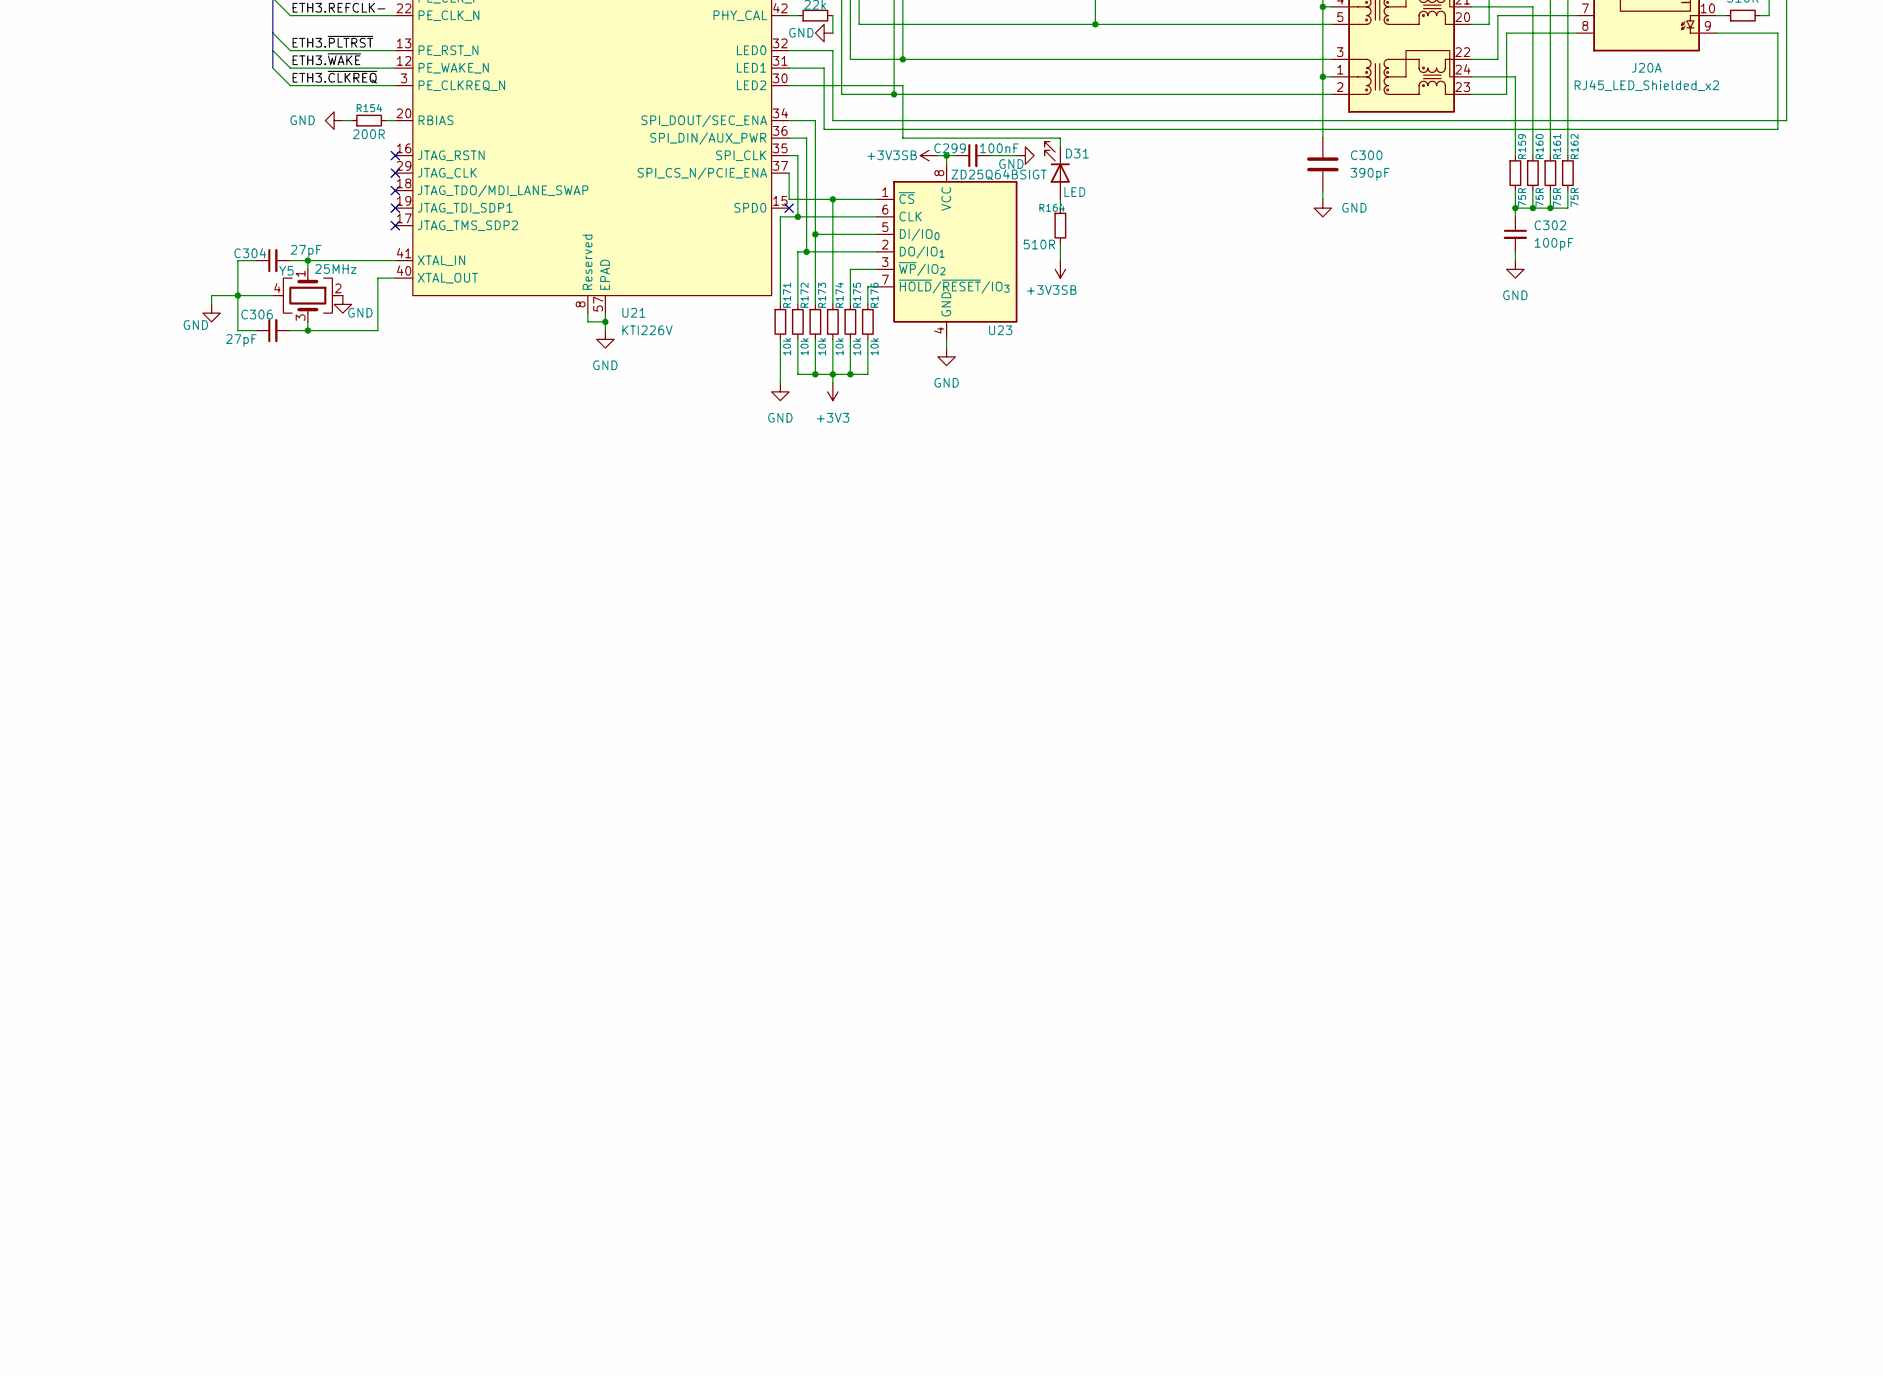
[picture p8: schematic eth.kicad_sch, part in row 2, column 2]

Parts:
C203, C204, C205, C206, C207, C208, C209, C210, C211, C212, C214, C215, C216, C217, C218, C219, C220, C222, C223, C226, C227, C228, C230, C231, C234, C235, C238, C239, C245, C247, C255, C256, C257, C258, C259, C260, C261, C262, C263, C264, C266, C267, C268, C269, C270, C271, C272, C274, C275, C278, C279, C280, C282, C283, C286, C287, C290, C291, C297, C299, C307, C308, C309, C310, C311, C312, C313, C315, C316, C317, C319, C320, C323, C324, C328: 100nF; C_0402_1005Metric
C213, C221, C224, C225, C229, C232, C233, C236, C237, C240, C265, C273, C276, C277, C281, C284, C285, C288, C289, C292, C314, C318, C321, C322, C325: 22uF; C_0603_1608Metric
C241, C242, C243, C244, C293, C294, C295, C296, C326, C327: 220nF; C_0402_1005Metric
C246, C248, C298, C300, C329: 390pF; C_0402_1005Metric
C249, C250, C301, C302, C330: 100pF; C_0402_1005Metric
C251, C252, C253, C254, C303, C304, C305, C306, C331, C332: 27pF; C_0402_1005Metric
D28, D29, D30, D31, D32: LED; LED_0603_1608Metric
J18, J20: RJ45_LED_Shielded_x2; RJ45-TH_HC-RJ45-059C
J19: RJE361882415; AMPHENOL_RJE361882415
L2, L3, L4, L5, L6: 1uH; L_0805_2012Metric
R109, R110, R111, R112, R131, R132, R133, R134, R135, R136, R137, R138, R139, R140, R141, R142, R143, R144, R145, R146, R165, R166, R167, R168, R169, R170, R171, R172, R173, R174, R175, R176, R177, R178, R188, R189, R190, R191, R192, R193: 10k; R_0402_1005Metric
R113, R114, R116, R118, R129, R130, R147, R148, R150, R152, R163, R164, R179, R181, R187: 510R; R_0402_1005Metric
R115, R117, R149, R151, R180: 22k; R_0402_1005Metric
R119, R120, R153, R154, R182: 200R; R_0402_1005Metric
R121, R122, R123, R124, R125, R126, R127, R128, R155, R156, R157, R158, R159, R160, R161, R162, R183, R184, R185, R186: 75R; R_0402_1005Metric
TR1, TR2, TR3, TR4, TR5: QG2439S
U8, U9, U10, U11, U16, U17, U18, U19, U24, U25: H5VU25U; Diodes_UDFN-10_1.0x2.5mm_P0.5mm
U12, U13, U20, U21, U26: KTI226V; QFN-56-1EP_7x7mm_P0.4mm_EP5.6x5.6mm_ThermalVias
U14, U15, U22, U23, U27: ZD25Q64BSIGT; SOIC-8_5.3x5.3mm_P1.27mm
Y2, Y3, Y4, Y5, Y6: 25MHz; Crystal_SMD_3225-4Pin_3.2x2.5mm

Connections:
+3V3: R132.2, R133.2, R134.2, R135.2, R136.2, R138.2, R139.2, R140.2, R141.2, R142.2, R166.2, R167.2, R168.2, R169.2, R170.2, R172.2, R173.2, R174.2, R175.2, R176.2, R189.2, R190.2, R191.2, R192.2, R193.2; also elsewhere on the board
+3V3SB: C203.2, C204.2, C205.1, C206.2, C207.2, C208.1, C211.2, C212.1, C213.2, C214.1, C217.2, C218.1, C221.2, C222.1, C225.2, C226.1, C229.2, C230.1, C233.2, C234.1, C237.2, C238.1, C245.1, C247.1, C255.2, C256.2, C257.1, C258.2, C259.2, C260.1, C263.2, C264.1, C265.2, C266.1, C269.2, C270.1, C273.2, C274.1, C277.2, C278.1, C281.2, C282.1, C285.2, C286.1, C289.2, C290.1, C297.1, C299.1, C307.2, C308.2, C309.1, C310.2, C311.1, C314.2, C315.1, C318.2, C319.1, C322.2, C323.1, C328.1, R109.1, R110.1, R111.1, R112.1, R113.2, R114.2, R116.2, R118.2, R129.2, R130.2, R143.1, R144.1, R145.1, R146.1, R147.2, R148.2, R150.2, R152.2, R163.2, R164.2, R177.1, R178.1, R179.2, R181.2, R187.2, U12.7 (+3.3V_DC), U12.14 (+3.3V_PAD), U12.23 (+3.3V_VPH), U12.33 (+3.3V_PAD), U12.39 (+3.3V_XO), U12.43 (+3.3V_CDB), U12.47 (+3.3V_A), U12.53 (+3.3V_A), U13.7 (+3.3V_DC), U13.14 (+3.3V_PAD), U13.23 (+3.3V_VPH), U13.33 (+3.3V_PAD), U13.39 (+3.3V_XO), U13.43 (+3.3V_CDB), U13.47 (+3.3V_A), U13.53 (+3.3V_A), U14.8 (VCC), U15.8 (VCC), U20.7 (+3.3V_DC), U20.14 (+3.3V_PAD), U20.23 (+3.3V_VPH), U20.33 (+3.3V_PAD), U20.39 (+3.3V_XO), U20.43 (+3.3V_CDB), U20.47 (+3.3V_A), U20.53 (+3.3V_A), U21.7 (+3.3V_DC), U21.14 (+3.3V_PAD), U21.23 (+3.3V_VPH), U21.33 (+3.3V_PAD), U21.39 (+3.3V_XO), U21.43 (+3.3V_CDB), U21.47 (+3.3V_A), U21.53 (+3.3V_A), U22.8 (VCC), U23.8 (VCC), U26.7 (+3.3V_DC), U26.14 (+3.3V_PAD), U26.23 (+3.3V_VPH), U26.33 (+3.3V_PAD), U26.39 (+3.3V_XO), U26.43 (+3.3V_CDB), U26.47 (+3.3V_A), U26.53 (+3.3V_A), U27.8 (VCC); also elsewhere on the board
/Module 1/ETH.REFCLK+: U12.21 (PE_CLK_P); also elsewhere on the board
/Module 1/ETH.REFCLK-: U12.22 (PE_CLK_N); also elsewhere on the board
/Module 1/ETH.Rx0+: C241.1; also elsewhere on the board
/Module 1/ETH.Rx0-: C242.1; also elsewhere on the board
/Module 1/ETH.SMBCLK: U12.11 (SMB_CLK); also elsewhere on the board
/Module 1/ETH.SMBDAT: U12.4 (ULP_WAKE_N), U12.10 (SMB_DATA); also elsewhere on the board
/Module 1/ETH.Tx0+: U12.28 (PE_Rx_P); also elsewhere on the board
/Module 1/ETH.Tx0-: U12.27 (PE_Rx_N); also elsewhere on the board
/Module 1/ETH.~CLKREQ: U12.3 (PE_CLKREQ_N); also elsewhere on the board
/Module 1/NVME.~PLTRST: U12.13 (PE_RST_N); also elsewhere on the board
/Module 1/NVME.~WAKE: U12.12 (PE_WAKE_N); also elsewhere on the board
/Module 2/ETH.REFCLK+: U13.21 (PE_CLK_P); also elsewhere on the board
/Module 2/ETH.REFCLK-: U13.22 (PE_CLK_N); also elsewhere on the board
/Module 2/ETH.Rx0+: C243.1; also elsewhere on the board
/Module 2/ETH.Rx0-: C244.1; also elsewhere on the board
/Module 2/ETH.SMBCLK: U13.11 (SMB_CLK); also elsewhere on the board
/Module 2/ETH.SMBDAT: U13.4 (ULP_WAKE_N), U13.10 (SMB_DATA); also elsewhere on the board
/Module 2/ETH.Tx0+: U13.28 (PE_Rx_P); also elsewhere on the board
/Module 2/ETH.Tx0-: U13.27 (PE_Rx_N); also elsewhere on the board
/Module 2/ETH.~CLKREQ: U13.3 (PE_CLKREQ_N); also elsewhere on the board
/Module 2/NVME.~PLTRST: U13.13 (PE_RST_N); also elsewhere on the board
/Module 2/NVME.~WAKE: U13.12 (PE_WAKE_N); also elsewhere on the board
/Module 3/ETH.REFCLK+: U20.21 (PE_CLK_P); also elsewhere on the board
/Module 3/ETH.REFCLK-: U20.22 (PE_CLK_N); also elsewhere on the board
/Module 3/ETH.Rx0+: C293.1; also elsewhere on the board
/Module 3/ETH.Rx0-: C294.1; also elsewhere on the board
/Module 3/ETH.SMBCLK: U20.11 (SMB_CLK); also elsewhere on the board
/Module 3/ETH.SMBDAT: U20.4 (ULP_WAKE_N), U20.10 (SMB_DATA); also elsewhere on the board
/Module 3/ETH.Tx0+: U20.28 (PE_Rx_P); also elsewhere on the board
/Module 3/ETH.Tx0-: U20.27 (PE_Rx_N); also elsewhere on the board
/Module 3/ETH.~CLKREQ: U20.3 (PE_CLKREQ_N); also elsewhere on the board
/Module 3/NVME.~PLTRST: U20.13 (PE_RST_N); also elsewhere on the board
/Module 3/NVME.~WAKE: U20.12 (PE_WAKE_N); also elsewhere on the board
/Module 4/ETH.REFCLK+: U21.21 (PE_CLK_P); also elsewhere on the board
/Module 4/ETH.REFCLK-: U21.22 (PE_CLK_N); also elsewhere on the board
/Module 4/ETH.Rx0+: C295.1; also elsewhere on the board
/Module 4/ETH.Rx0-: C296.1; also elsewhere on the board
/Module 4/ETH.Tx0+: U21.28 (PE_Rx_P); also elsewhere on the board
/Module 4/ETH.Tx0-: U21.27 (PE_Rx_N); also elsewhere on the board
/Module 4/ETH.~CLKREQ: U21.3 (PE_CLKREQ_N); also elsewhere on the board
/Module 4/NVME.~PLTRST: U21.13 (PE_RST_N); also elsewhere on the board
/Module 4/NVME.~WAKE: U21.12 (PE_WAKE_N); also elsewhere on the board
/Module 4/PCIE_X4.SMBCLK: U21.11 (SMB_CLK); also elsewhere on the board
/Module 4/PCIE_X4.SMBDAT: U21.4 (ULP_WAKE_N), U21.10 (SMB_DATA); also elsewhere on the board
/Module 5/ETH.REFCLK+: U26.21 (PE_CLK_P); also elsewhere on the board
/Module 5/ETH.REFCLK-: U26.22 (PE_CLK_N); also elsewhere on the board
/Module 5/ETH.Rx0+: C326.1; also elsewhere on the board
/Module 5/ETH.Rx0-: C327.1; also elsewhere on the board
/Module 5/ETH.Tx0+: U26.28 (PE_Rx_P); also elsewhere on the board
/Module 5/ETH.Tx0-: U26.27 (PE_Rx_N); also elsewhere on the board
/Module 5/ETH.~CLKREQ: U26.3 (PE_CLKREQ_N); also elsewhere on the board
/Module 5/NVME.~PLTRST: U26.13 (PE_RST_N); also elsewhere on the board
/Module 5/NVME.~WAKE: U26.12 (PE_WAKE_N); also elsewhere on the board
/Module 5/PCIE_X4.SMBCLK: U26.11 (SMB_CLK); also elsewhere on the board
/Module 5/PCIE_X4.SMBDAT: U26.4 (ULP_WAKE_N), U26.10 (SMB_DATA); also elsewhere on the board
unnamed: C246.2, TR1.1 (CT), TR1.4 (CT), TR1.7 (CT), TR1.10 (CT)
unnamed: C248.2, TR2.1 (CT), TR2.4 (CT), TR2.7 (CT), TR2.10 (CT)
unnamed: C249.1, R121.2, R122.2, R123.2, R124.2
unnamed: C250.1, R125.2, R126.2, R127.2, R128.2
unnamed: C298.1, TR3.1 (CT), TR3.4 (CT), TR3.7 (CT), TR3.10 (CT)
unnamed: C300.1, TR4.1 (CT), TR4.4 (CT), TR4.7 (CT), TR4.10 (CT)
unnamed: C301.1, R155.2, R156.2, R157.2, R158.2
unnamed: C302.1, R159.2, R160.2, R161.2, R162.2
unnamed: C329.1, TR5.1 (CT), TR5.4 (CT), TR5.7 (CT), TR5.10 (CT)
unnamed: C330.1, R183.2, R184.2, R185.2, R186.2
unnamed: D28.2 (A), R129.1
unnamed: D28.1 (K), U12.30 (LED2)
unnamed: D29.2 (A), R130.1
unnamed: D29.1 (K), U13.30 (LED2)
unnamed: D30.2 (A), R163.1
unnamed: D30.1 (K), U20.30 (LED2)
unnamed: D31.2 (A), R164.1
unnamed: D31.1 (K), U21.30 (LED2)
unnamed: D32.2 (A), R187.1
unnamed: D32.1 (K), U26.30 (LED2)
unnamed: J18.10, R118.1
unnamed: J18.12, R114.1
unnamed: J18.22, R150.1
unnamed: J18.24, R147.1
unnamed: J19.D1, R116.1
unnamed: J19.D3, R113.1
unnamed: J20.10, R152.1
unnamed: J20.12, R148.1
unnamed: J20.22, R181.1
unnamed: J20.24, R179.1
unnamed: L2.2, U12.5 (VDD_CTRL), U12.6 (VDD_CTRL)
unnamed: L3.2, U13.5 (VDD_CTRL), U13.6 (VDD_CTRL)
unnamed: L4.2, U20.5 (VDD_CTRL), U20.6 (VDD_CTRL)
unnamed: L5.2, U21.5 (VDD_CTRL), U21.6 (VDD_CTRL)
unnamed: L6.2, U26.5 (VDD_CTRL), U26.6 (VDD_CTRL)
unnamed: R121.1, TR1.24 (CT)
unnamed: R122.1, TR1.21 (CT)
unnamed: R123.1, TR1.18 (CT)
unnamed: R124.1, TR1.15 (CT)
unnamed: R125.1, TR2.24 (CT)
unnamed: R126.1, TR2.21 (CT)
unnamed: R127.1, TR2.18 (CT)
unnamed: R128.1, TR2.15 (CT)
unnamed: R155.1, TR3.24 (CT)
unnamed: R156.1, TR3.21 (CT)
unnamed: R157.1, TR3.18 (CT)
unnamed: R158.1, TR3.15 (CT)
unnamed: R159.1, TR4.24 (CT)
unnamed: R160.1, TR4.21 (CT)
unnamed: R161.1, TR4.18 (CT)
unnamed: R162.1, TR4.15 (CT)
unnamed: R183.1, TR5.24 (CT)
unnamed: R184.1, TR5.21 (CT)
unnamed: R185.1, TR5.18 (CT)
unnamed: R186.1, TR5.15 (CT)
unnamed: J19.8, TR1.23 (MX1+)
unnamed: J19.7, TR1.22 (MX1-)
unnamed: J19.5, TR1.20 (MX2+)
unnamed: J19.4, TR1.19 (MX2-)
unnamed: J19.6, TR1.17 (MX3+)
unnamed: J19.3, TR1.16 (MX3-)
unnamed: J19.2, TR1.14 (MX4+)
unnamed: J19.1, TR1.13 (MX4-)
unnamed: TR1.2 (TD1+), U8.1, U12.55 (MDI_D_N)
unnamed: TR1.3 (TD1-), U8.2, U12.54 (MDI_D_P)
unnamed: TR1.5 (TD2+), U8.5, U12.52 (MDI_C_N)
unnamed: TR1.6 (TD2-), U8.4, U12.51 (MDI_C_P)
unnamed: TR1.8 (TD3+), U9.1, U12.49 (MDI_B_N)
unnamed: TR1.9 (TD3-), U9.2, U12.48 (MDI_B_P)
unnamed: TR1.11 (TD4+), U9.5, U12.46 (MDI_A_N)
unnamed: TR1.12 (TD4-), U9.4, U12.45 (MDI_A_P)
unnamed: J18.8, TR2.23 (MX1+)
unnamed: J18.7, TR2.22 (MX1-)
unnamed: J18.5, TR2.20 (MX2+)
unnamed: J18.4, TR2.19 (MX2-)
unnamed: J18.6, TR2.17 (MX3+)
unnamed: J18.3, TR2.16 (MX3-)
unnamed: J18.2, TR2.14 (MX4+)
unnamed: J18.1, TR2.13 (MX4-)
unnamed: TR2.2 (TD1+), U10.1, U13.55 (MDI_D_N)
unnamed: TR2.3 (TD1-), U10.2, U13.54 (MDI_D_P)
unnamed: TR2.5 (TD2+), U10.5, U13.52 (MDI_C_N)
unnamed: TR2.6 (TD2-), U10.4, U13.51 (MDI_C_P)
unnamed: TR2.8 (TD3+), U11.1, U13.49 (MDI_B_N)
unnamed: TR2.9 (TD3-), U11.2, U13.48 (MDI_B_P)
unnamed: TR2.11 (TD4+), U11.5, U13.46 (MDI_A_N)
unnamed: TR2.12 (TD4-), U11.4, U13.45 (MDI_A_P)
unnamed: J18.20, TR3.23 (MX1+)
unnamed: J18.19, TR3.22 (MX1-)
unnamed: J18.17, TR3.20 (MX2+)
unnamed: J18.16, TR3.19 (MX2-)
unnamed: J18.18, TR3.17 (MX3+)
unnamed: J18.15, TR3.16 (MX3-)
unnamed: J18.14, TR3.14 (MX4+)
unnamed: J18.13, TR3.13 (MX4-)
unnamed: TR3.2 (TD1+), U16.1, U20.55 (MDI_D_N)
unnamed: TR3.3 (TD1-), U16.2, U20.54 (MDI_D_P)
unnamed: TR3.5 (TD2+), U16.5, U20.52 (MDI_C_N)
unnamed: TR3.6 (TD2-), U16.4, U20.51 (MDI_C_P)
unnamed: TR3.8 (TD3+), U17.1, U20.49 (MDI_B_N)
unnamed: TR3.9 (TD3-), U17.2, U20.48 (MDI_B_P)
unnamed: TR3.11 (TD4+), U17.5, U20.46 (MDI_A_N)
unnamed: TR3.12 (TD4-), U17.4, U20.45 (MDI_A_P)
unnamed: J20.8, TR4.23 (MX1+)
unnamed: J20.7, TR4.22 (MX1-)
unnamed: J20.5, TR4.20 (MX2+)
unnamed: J20.4, TR4.19 (MX2-)
unnamed: J20.6, TR4.17 (MX3+)
unnamed: J20.3, TR4.16 (MX3-)
unnamed: J20.2, TR4.14 (MX4+)
unnamed: J20.1, TR4.13 (MX4-)
unnamed: TR4.2 (TD1+), U18.1, U21.55 (MDI_D_N)
unnamed: TR4.3 (TD1-), U18.2, U21.54 (MDI_D_P)
unnamed: TR4.5 (TD2+), U18.5, U21.52 (MDI_C_N)
unnamed: TR4.6 (TD2-), U18.4, U21.51 (MDI_C_P)
unnamed: TR4.8 (TD3+), U19.1, U21.49 (MDI_B_N)
unnamed: TR4.9 (TD3-), U19.2, U21.48 (MDI_B_P)
unnamed: TR4.11 (TD4+), U19.5, U21.46 (MDI_A_N)
unnamed: TR4.12 (TD4-), U19.4, U21.45 (MDI_A_P)
unnamed: J20.20, TR5.23 (MX1+)
unnamed: J20.19, TR5.22 (MX1-)
unnamed: J20.17, TR5.20 (MX2+)
unnamed: J20.16, TR5.19 (MX2-)
unnamed: J20.18, TR5.17 (MX3+)
unnamed: J20.15, TR5.16 (MX3-)
unnamed: J20.14, TR5.14 (MX4+)
unnamed: J20.13, TR5.13 (MX4-)
unnamed: TR5.2 (TD1+), U24.1, U26.55 (MDI_D_N)
unnamed: TR5.3 (TD1-), U24.2, U26.54 (MDI_D_P)
unnamed: TR5.5 (TD2+), U24.5, U26.52 (MDI_C_N)
unnamed: TR5.6 (TD2-), U24.4, U26.51 (MDI_C_P)
unnamed: TR5.8 (TD3+), U25.1, U26.49 (MDI_B_N)
unnamed: TR5.9 (TD3-), U25.2, U26.48 (MDI_B_P)
unnamed: TR5.11 (TD4+), U25.5, U26.46 (MDI_A_N)
unnamed: TR5.12 (TD4-), U25.4, U26.45 (MDI_A_P)
unnamed: R109.2, U12.2 (LAN_DISABLE_N)
unnamed: R110.2, U12.1 (LAN_PWR_GOOD)
unnamed: J19.D4, U12.32 (LED0)
unnamed: J19.D2, U12.31 (LED1)
unnamed: C242.2, U12.24 (PE_Tx_N)
unnamed: C241.2, U12.25 (PE_Tx_P)
unnamed: R115.1, U12.42 (PHY_CAL)
unnamed: R119.2, U12.20 (RBIAS)
unnamed: R131.1, U12.35 (SPI_CLK), U14.6 (CLK)
unnamed: R134.1, U12.37 (SPI_CS_N/PCIE_ENA), U14.1 (~CS)
unnamed: R132.1, U12.36 (SPI_DIN/AUX_PWR), U14.2 (DO/IO_{1})
unnamed: R133.1, U12.34 (SPI_DOUT/SEC_ENA), U14.5 (DI/IO_{0})
unnamed: C209.2, C210.1, C215.2, C216.1, C223.2, C224.1, C231.2, C232.1, L2.1, U12.9 (VDD_CORE), U12.26 (VDD_VP), U12.38 (VDD_CORE), U12.44 (VDD_A), U12.50 (VDD_A), U12.56 (VDD_A)
unnamed: C251.2, U12.41 (XTAL_IN), Y2.1
unnamed: C253.2, U12.40 (XTAL_OUT), Y2.3
unnamed: R111.2, U13.2 (LAN_DISABLE_N)
unnamed: R112.2, U13.1 (LAN_PWR_GOOD)
unnamed: J18.11, U13.32 (LED0)
unnamed: J18.9, U13.31 (LED1)
unnamed: C244.2, U13.24 (PE_Tx_N)
unnamed: C243.2, U13.25 (PE_Tx_P)
unnamed: R117.1, U13.42 (PHY_CAL)
unnamed: R120.2, U13.20 (RBIAS)
unnamed: R137.1, U13.35 (SPI_CLK), U15.6 (CLK)
unnamed: R140.1, U13.37 (SPI_CS_N/PCIE_ENA), U15.1 (~CS)
unnamed: R138.1, U13.36 (SPI_DIN/AUX_PWR), U15.2 (DO/IO_{1})
unnamed: R139.1, U13.34 (SPI_DOUT/SEC_ENA), U15.5 (DI/IO_{0})
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

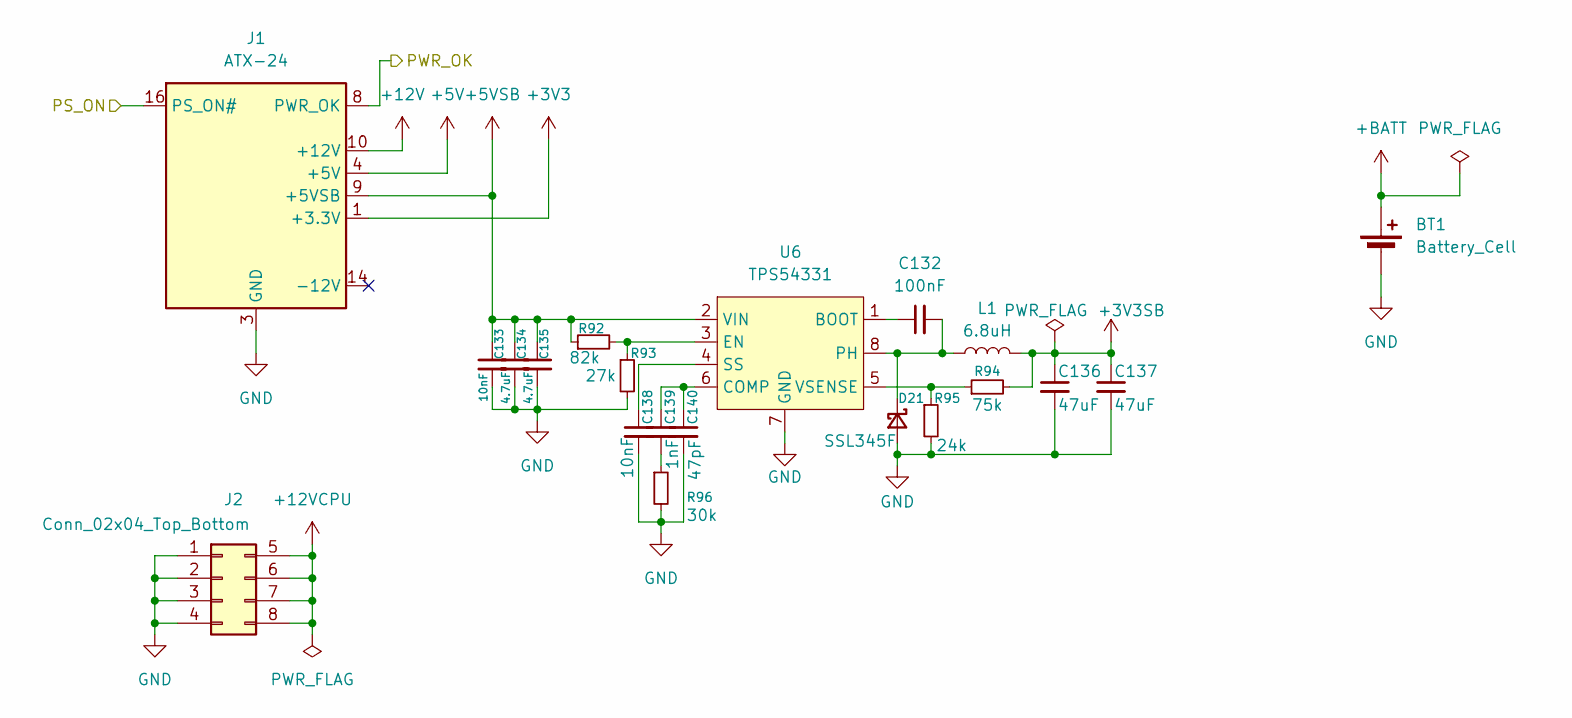
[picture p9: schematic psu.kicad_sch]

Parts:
BT1: Battery_Cell; BAT-TH_BH-123A-A5BJ002
C132: 100nF; C_0402_1005Metric
C133, C138: 10nF; C_0402_1005Metric
C134, C135: 4.7uF; C_0402_1005Metric
C136, C137: 47uF; C_0805_2012Metric
C139: 1nF; C_0402_1005Metric
C140: 47pF; C_0402_1005Metric
D21: SSL345F; D_SMA
J1: ATX-24; Molex_Mini-Fit_Jr_5566-24A_2x12_P4.20mm_Vertical
J2: Conn_02x04_Top_Bottom; Molex_Mini-Fit_Jr_5566-08A_2x04_P4.20mm_Vertical
L1: 6.8uH; L_7.3x7.3_H3.5
R92: 82k; R_0603_1608Metric
R93: 27k; R_0603_1608Metric
R94: 75k; R_0402_1005Metric
R95: 24k; R_0402_1005Metric
R96: 30k; R_0603_1608Metric
U6: TPS54331; SOIC-8_3.9x4.9mm_P1.27mm

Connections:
+3V3: J1.1 (+3.3V), J1.2 (+3.3V), J1.12 (+3.3V), J1.13 (+3.3V); also elsewhere on the board
+3V3SB: C136.1, C137.1, L1.2, R94.2; also elsewhere on the board
+5V: J1.4 (+5V), J1.6 (+5V), J1.21 (+5V), J1.22 (+5V), J1.23 (+5V); also elsewhere on the board
+5VSB: C133.1, C134.1, C135.1, J1.9 (+5VSB), R92.1, U6.2 (VIN); also elsewhere on the board
+12V: J1.10 (+12V), J1.11 (+12V); also elsewhere on the board
+12VCPU: J2.5, J2.6, J2.7, J2.8; also elsewhere on the board
+BATT: BT1.1 (+); also elsewhere on the board
/PSU/PS_ON: J1.16 (PS_ON#); also elsewhere on the board
/PSU/PWR_OK: J1.8 (PWR_OK); also elsewhere on the board
unnamed: C139.2, R96.1
unnamed: C132.2, D21.1 (K), L1.1, U6.8 (PH)
unnamed: C132.1, U6.1 (BOOT)
unnamed: C139.1, C140.1, U6.6 (COMP)
unnamed: R92.2, R93.1, U6.3 (EN)
unnamed: C138.1, U6.4 (SS)
unnamed: R94.1, R95.1, U6.5 (VSENSE)

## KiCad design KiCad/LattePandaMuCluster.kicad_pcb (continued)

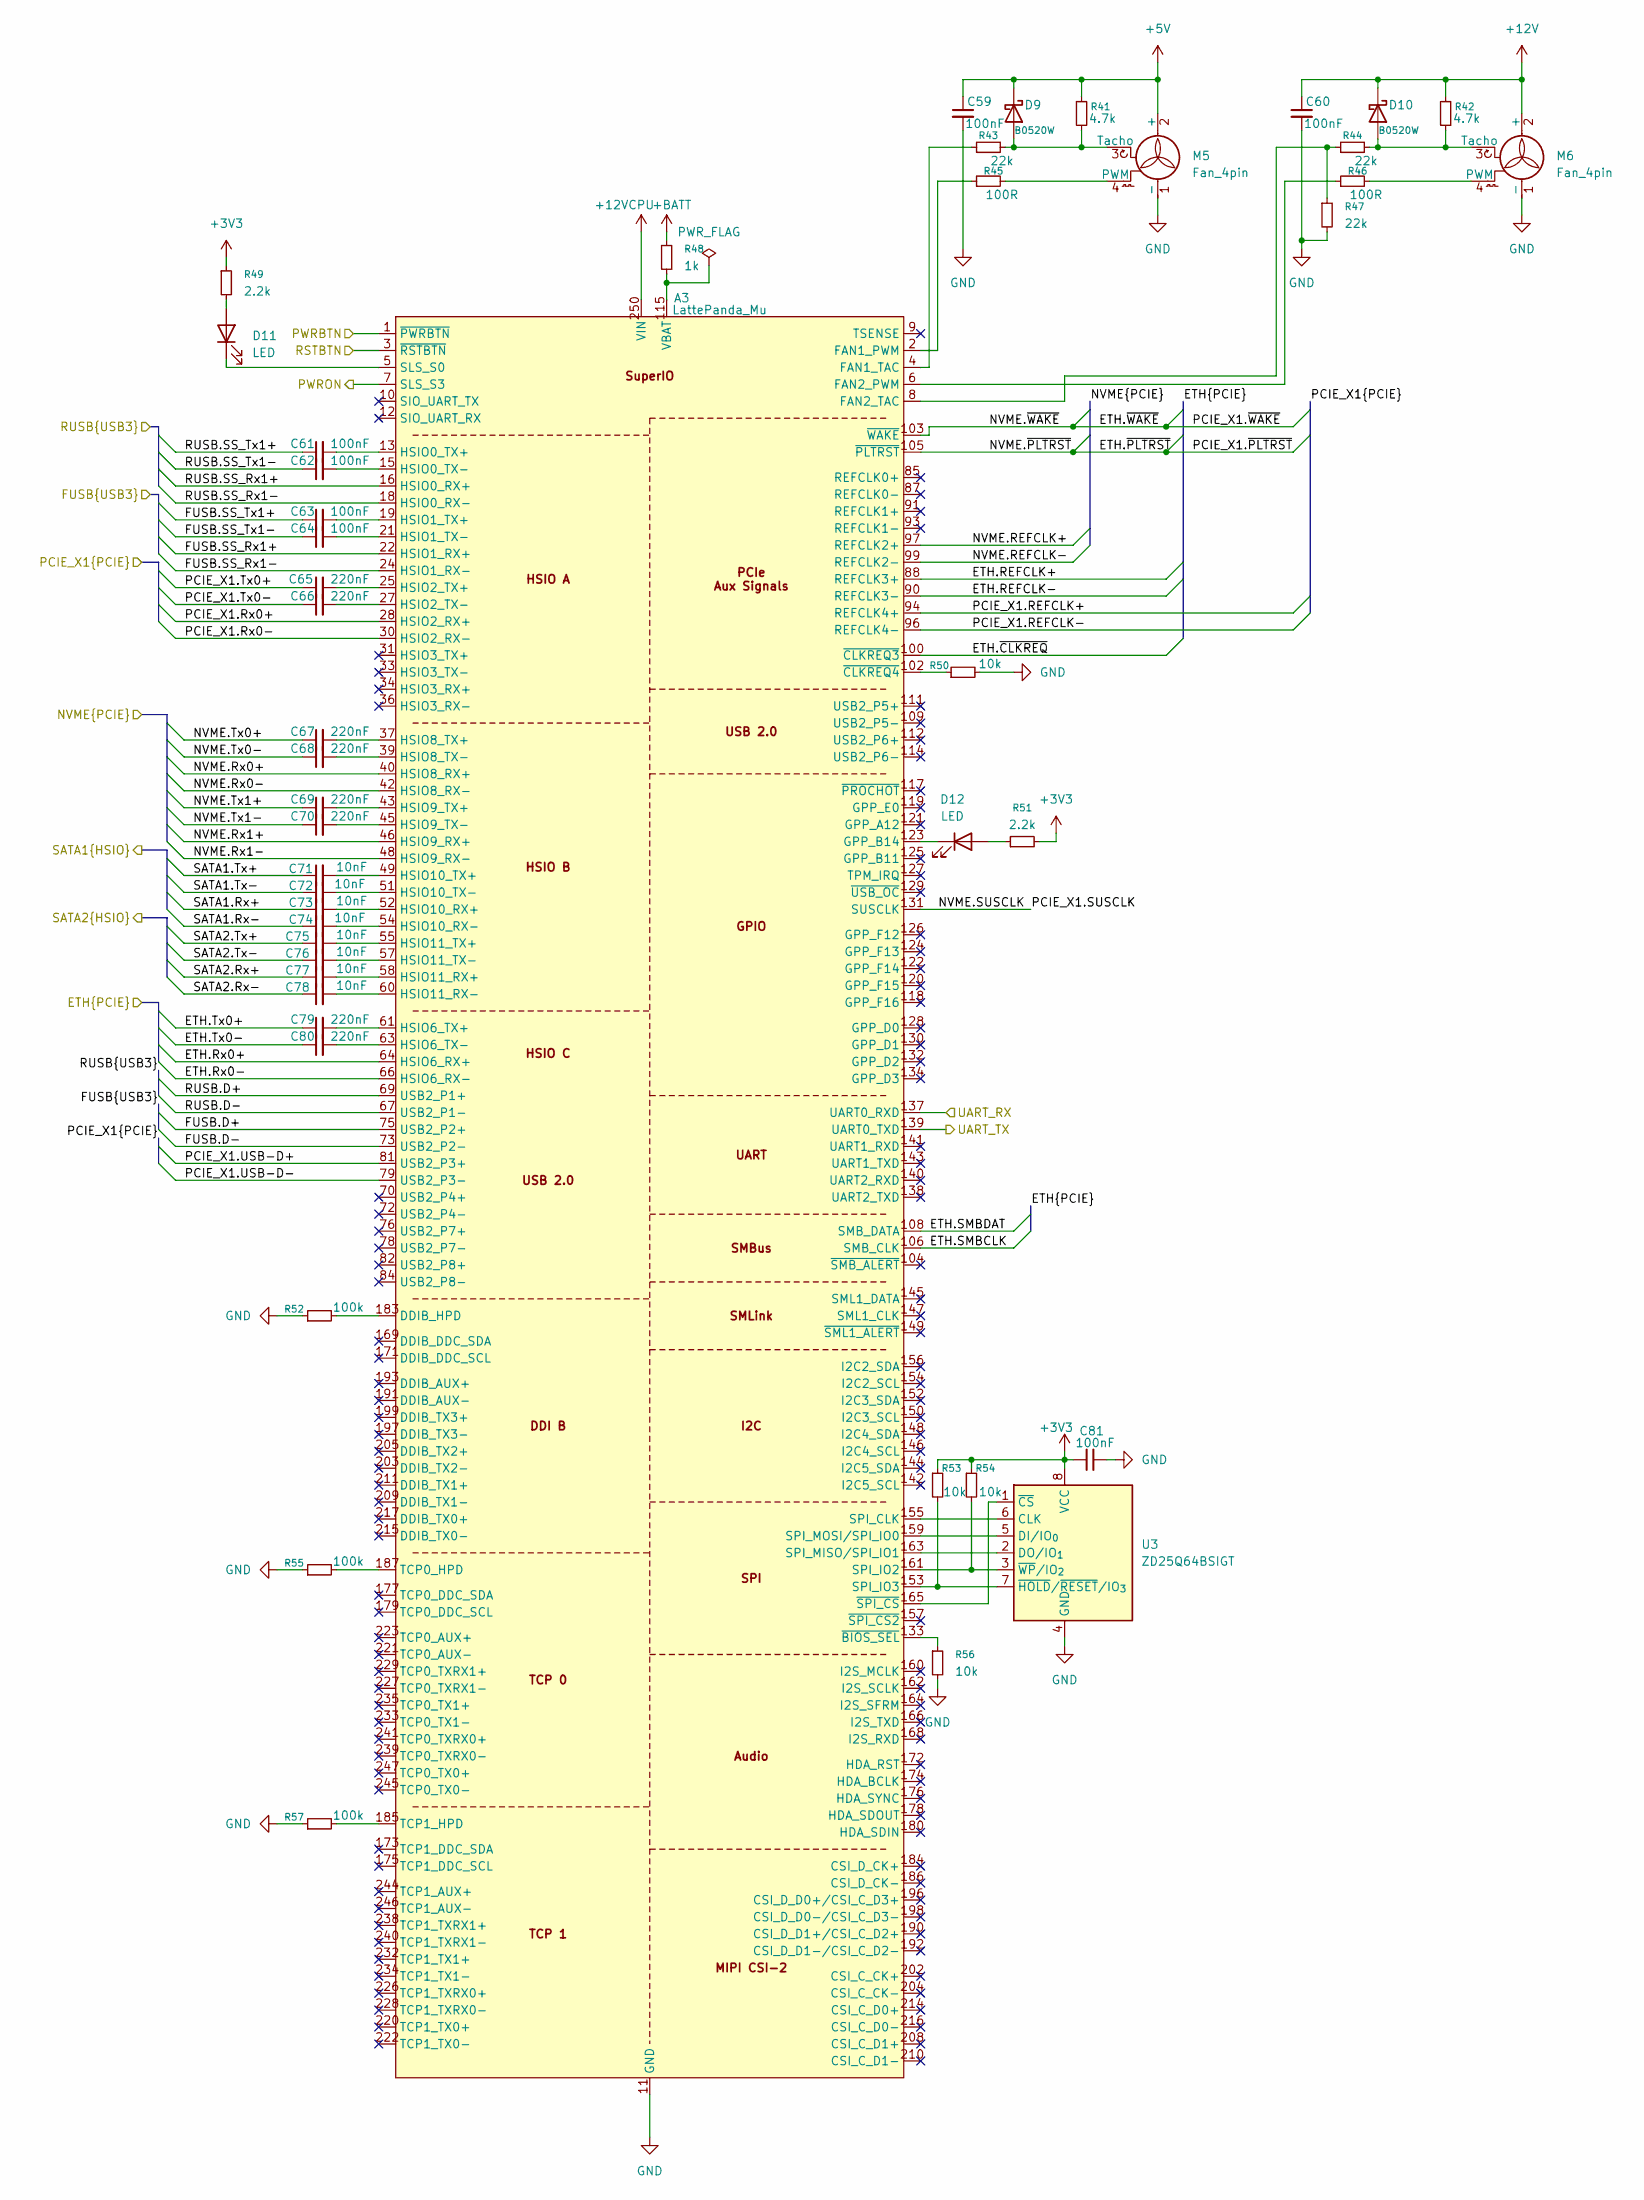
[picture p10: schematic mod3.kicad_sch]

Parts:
A3: LattePanda_Mu; ATTEND_124B-150A02
C59, C60, C61, C62, C63, C64, C81: 100nF; C_0402_1005Metric
C65, C66, C67, C68, C69, C70, C79, C80: 220nF; C_0402_1005Metric
C71, C72, C73, C74, C75, C76, C77, C78: 10nF; C_0402_1005Metric
D9, D10: B0520W; D_SOD-123
D11, D12: LED; LED_0603_1608Metric
M5: Fan_4pin; JST_PH_B4B-PH-K_1x04_P2.00mm_Vertical
M6: Fan_4pin; FanPinHeader_1x04_P2.54mm_Vertical
R41, R42: 4.7k; R_0402_1005Metric
R43, R44, R47: 22k; R_0402_1005Metric
R45, R46: 100R; R_0402_1005Metric
R48: 1k; R_0805_2012Metric
R49, R51: 2.2k; R_0402_1005Metric
R50, R53, R54, R56: 10k; R_0402_1005Metric
R52, R55, R57: 100k; R_0402_1005Metric
U3: ZD25Q64BSIGT; SOIC-8_5.3x5.3mm_P1.27mm

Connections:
+3V3: C81.1, R49.1, R51.2, R53.1, R54.1, U3.8 (VCC); also elsewhere on the board
+5V: C59.1, D9.1 (K), M5.2 (+), R41.1; also elsewhere on the board
+12V: C60.1, D10.1 (K), M6.2 (+), R42.1; also elsewhere on the board
+12VCPU: A3.250 (VIN), A3.251 (VIN), A3.252 (VIN), A3.253 (VIN), A3.254 (VIN), A3.255 (VIN), A3.256 (VIN), A3.257 (VIN), A3.258 (VIN), A3.259 (VIN), A3.260 (VIN); also elsewhere on the board
+BATT: R48.1; also elsewhere on the board
/Module 1/SLOT3_UART_RX: A3.139 (UART0_TXD); also elsewhere on the board
/Module 1/SLOT3_UART_TX: A3.137 (UART0_RXD); also elsewhere on the board
/Module 3/ETH.REFCLK+: A3.88 (REFCLK3+); also elsewhere on the board
/Module 3/ETH.REFCLK-: A3.90 (REFCLK3-); also elsewhere on the board
/Module 3/ETH.Rx0+: A3.64 (HSIO6_RX+); also elsewhere on the board
/Module 3/ETH.Rx0-: A3.66 (HSIO6_RX-); also elsewhere on the board
/Module 3/ETH.SMBCLK: A3.106 (SMB_CLK); also elsewhere on the board
/Module 3/ETH.SMBDAT: A3.108 (SMB_DATA); also elsewhere on the board
/Module 3/ETH.Tx0+: C79.1; also elsewhere on the board
/Module 3/ETH.Tx0-: C80.1; also elsewhere on the board
/Module 3/ETH.~CLKREQ: A3.100 (~CLKREQ3); also elsewhere on the board
/Module 3/FUSB.D+: A3.75 (USB2_P2+); also elsewhere on the board
/Module 3/FUSB.D-: A3.73 (USB2_P2-); also elsewhere on the board
/Module 3/FUSB.SS_Rx1+: A3.22 (HSIO1_RX+); also elsewhere on the board
/Module 3/FUSB.SS_Rx1-: A3.24 (HSIO1_RX-); also elsewhere on the board
/Module 3/FUSB.SS_Tx1+: C63.1; also elsewhere on the board
/Module 3/FUSB.SS_Tx1-: C64.1; also elsewhere on the board
/Module 3/NVME.REFCLK+: A3.97 (REFCLK2+); also elsewhere on the board
/Module 3/NVME.REFCLK-: A3.99 (REFCLK2-); also elsewhere on the board
/Module 3/NVME.Rx0+: A3.40 (HSIO8_RX+); also elsewhere on the board
/Module 3/NVME.Rx0-: A3.42 (HSIO8_RX-); also elsewhere on the board
/Module 3/NVME.Rx1+: A3.46 (HSIO9_RX+); also elsewhere on the board
/Module 3/NVME.Rx1-: A3.48 (HSIO9_RX-); also elsewhere on the board
/Module 3/NVME.SUSCLK: A3.131 (SUSCLK); also elsewhere on the board
/Module 3/NVME.Tx0+: C67.1; also elsewhere on the board
/Module 3/NVME.Tx0-: C68.1; also elsewhere on the board
/Module 3/NVME.Tx1+: C69.1; also elsewhere on the board
/Module 3/NVME.Tx1-: C70.1; also elsewhere on the board
/Module 3/NVME.~PLTRST: A3.105 (~PLTRST); also elsewhere on the board
/Module 3/NVME.~WAKE: A3.103 (~WAKE); also elsewhere on the board
/Module 3/PCIE_X1.REFCLK+: A3.94 (REFCLK4+); also elsewhere on the board
/Module 3/PCIE_X1.REFCLK-: A3.96 (REFCLK4-); also elsewhere on the board
/Module 3/PCIE_X1.Rx0+: A3.28 (HSIO2_RX+); also elsewhere on the board
/Module 3/PCIE_X1.Rx0-: A3.30 (HSIO2_RX-); also elsewhere on the board
/Module 3/PCIE_X1.Tx0+: C65.1; also elsewhere on the board
/Module 3/PCIE_X1.Tx0-: C66.1; also elsewhere on the board
/Module 3/PCIE_X1.USB-D+: A3.81 (USB2_P3+)
/Module 3/PCIE_X1.USB-D-: A3.79 (USB2_P3-)
/Module 3/RUSB.D+: A3.69 (USB2_P1+); also elsewhere on the board
/Module 3/RUSB.D-: A3.67 (USB2_P1-); also elsewhere on the board
/Module 3/RUSB.SS_Rx1+: A3.16 (HSIO0_RX+); also elsewhere on the board
/Module 3/RUSB.SS_Rx1-: A3.18 (HSIO0_RX-); also elsewhere on the board
/Module 3/RUSB.SS_Tx1+: C61.1; also elsewhere on the board
/Module 3/RUSB.SS_Tx1-: C62.1; also elsewhere on the board
/Module 3/SATA1.Rx+: C73.1; also elsewhere on the board
/Module 3/SATA1.Rx-: C74.1; also elsewhere on the board
/Module 3/SATA1.Tx+: C71.1; also elsewhere on the board
/Module 3/SATA1.Tx-: C72.1; also elsewhere on the board
/Module 3/SATA2.Rx+: C77.1; also elsewhere on the board
/Module 3/SATA2.Rx-: C78.1; also elsewhere on the board
/Module 3/SATA2.Tx+: C75.1; also elsewhere on the board
/Module 3/SATA2.Tx-: C76.1; also elsewhere on the board
/STM32/PWRBTN3: A3.1 (~PWRBTN); also elsewhere on the board
/STM32/PWRON3: A3.7 (SLS_S3); also elsewhere on the board
/STM32/RSTBTN3: A3.3 (~RSTBTN); also elsewhere on the board
unnamed: A3.183 (DDIB_HPD), R52.2
unnamed: A3.2 (FAN1_PWM), R45.1
unnamed: A3.4 (FAN1_TAC), R43.1
unnamed: A3.6 (FAN2_PWM), R46.1
unnamed: A3.8 (FAN2_TAC), R44.1, R47.1
unnamed: A3.123 (GPP_B14), D12.1 (K)
unnamed: A3.13 (HSIO0_TX+), C61.2
unnamed: A3.15 (HSIO0_TX-), C62.2
unnamed: A3.19 (HSIO1_TX+), C63.2
unnamed: A3.21 (HSIO1_TX-), C64.2
unnamed: A3.25 (HSIO2_TX+), C65.2
unnamed: A3.27 (HSIO2_TX-), C66.2
unnamed: A3.61 (HSIO6_TX+), C79.2
unnamed: A3.63 (HSIO6_TX-), C80.2
unnamed: A3.37 (HSIO8_TX+), C67.2
unnamed: A3.39 (HSIO8_TX-), C68.2
unnamed: A3.43 (HSIO9_TX+), C69.2
unnamed: A3.45 (HSIO9_TX-), C70.2
unnamed: A3.52 (HSIO10_RX+), C73.2
unnamed: A3.54 (HSIO10_RX-), C74.2
unnamed: A3.49 (HSIO10_TX+), C71.2
unnamed: A3.51 (HSIO10_TX-), C72.2
unnamed: A3.58 (HSIO11_RX+), C77.2
unnamed: A3.60 (HSIO11_RX-), C78.2
unnamed: A3.55 (HSIO11_TX+), C75.2
unnamed: A3.57 (HSIO11_TX-), C76.2
unnamed: A3.5 (SLS_S0), D11.1 (K)
unnamed: A3.155 (SPI_CLK), U3.6 (CLK)
unnamed: A3.161 (SPI_IO2), R54.2, U3.3 (~WP/IO_{2})
unnamed: A3.153 (SPI_IO3), R53.2, U3.7 (~HOLD/~RESET/IO_{3})
unnamed: A3.163 (SPI_MISO/SPI_IO1), U3.2 (DO/IO_{1})
unnamed: A3.159 (SPI_MOSI/SPI_IO0), U3.5 (DI/IO_{0})
unnamed: A3.185 (TCP1_HPD), R57.2
unnamed: A3.115 (VBAT), R48.2
unnamed: A3.133 (~BIOS_SEL), R56.1
unnamed: A3.165 (~SPI_CS), U3.1 (~CS)
unnamed: D9.2 (A), M5.3 (Tacho), R41.2, R43.2
unnamed: D10.2 (A), M6.3 (Tacho), R42.2, R44.2
unnamed: D11.2 (A), R49.2
unnamed: D12.2 (A), R51.1
unnamed: M5.4 (PWM), R45.2
unnamed: M6.4 (PWM), R46.2

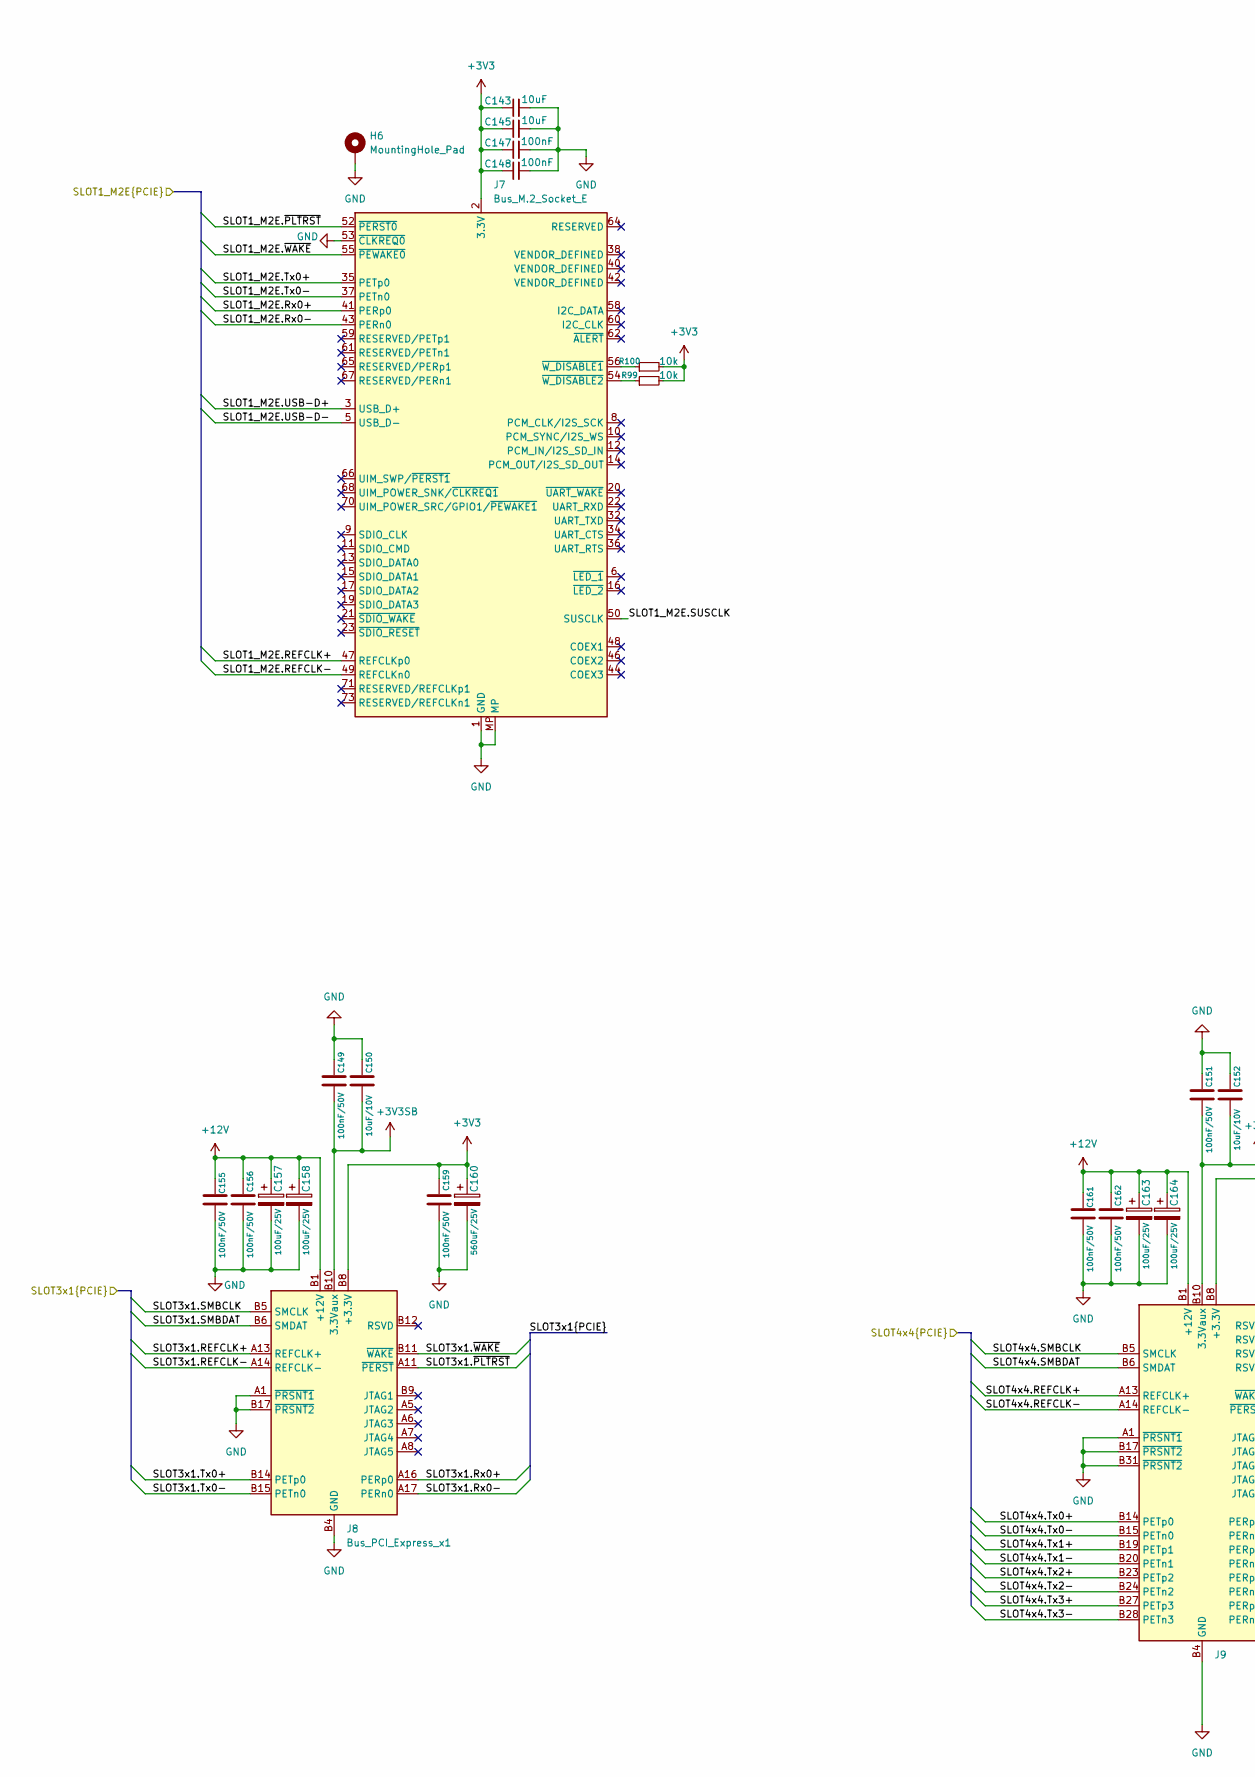
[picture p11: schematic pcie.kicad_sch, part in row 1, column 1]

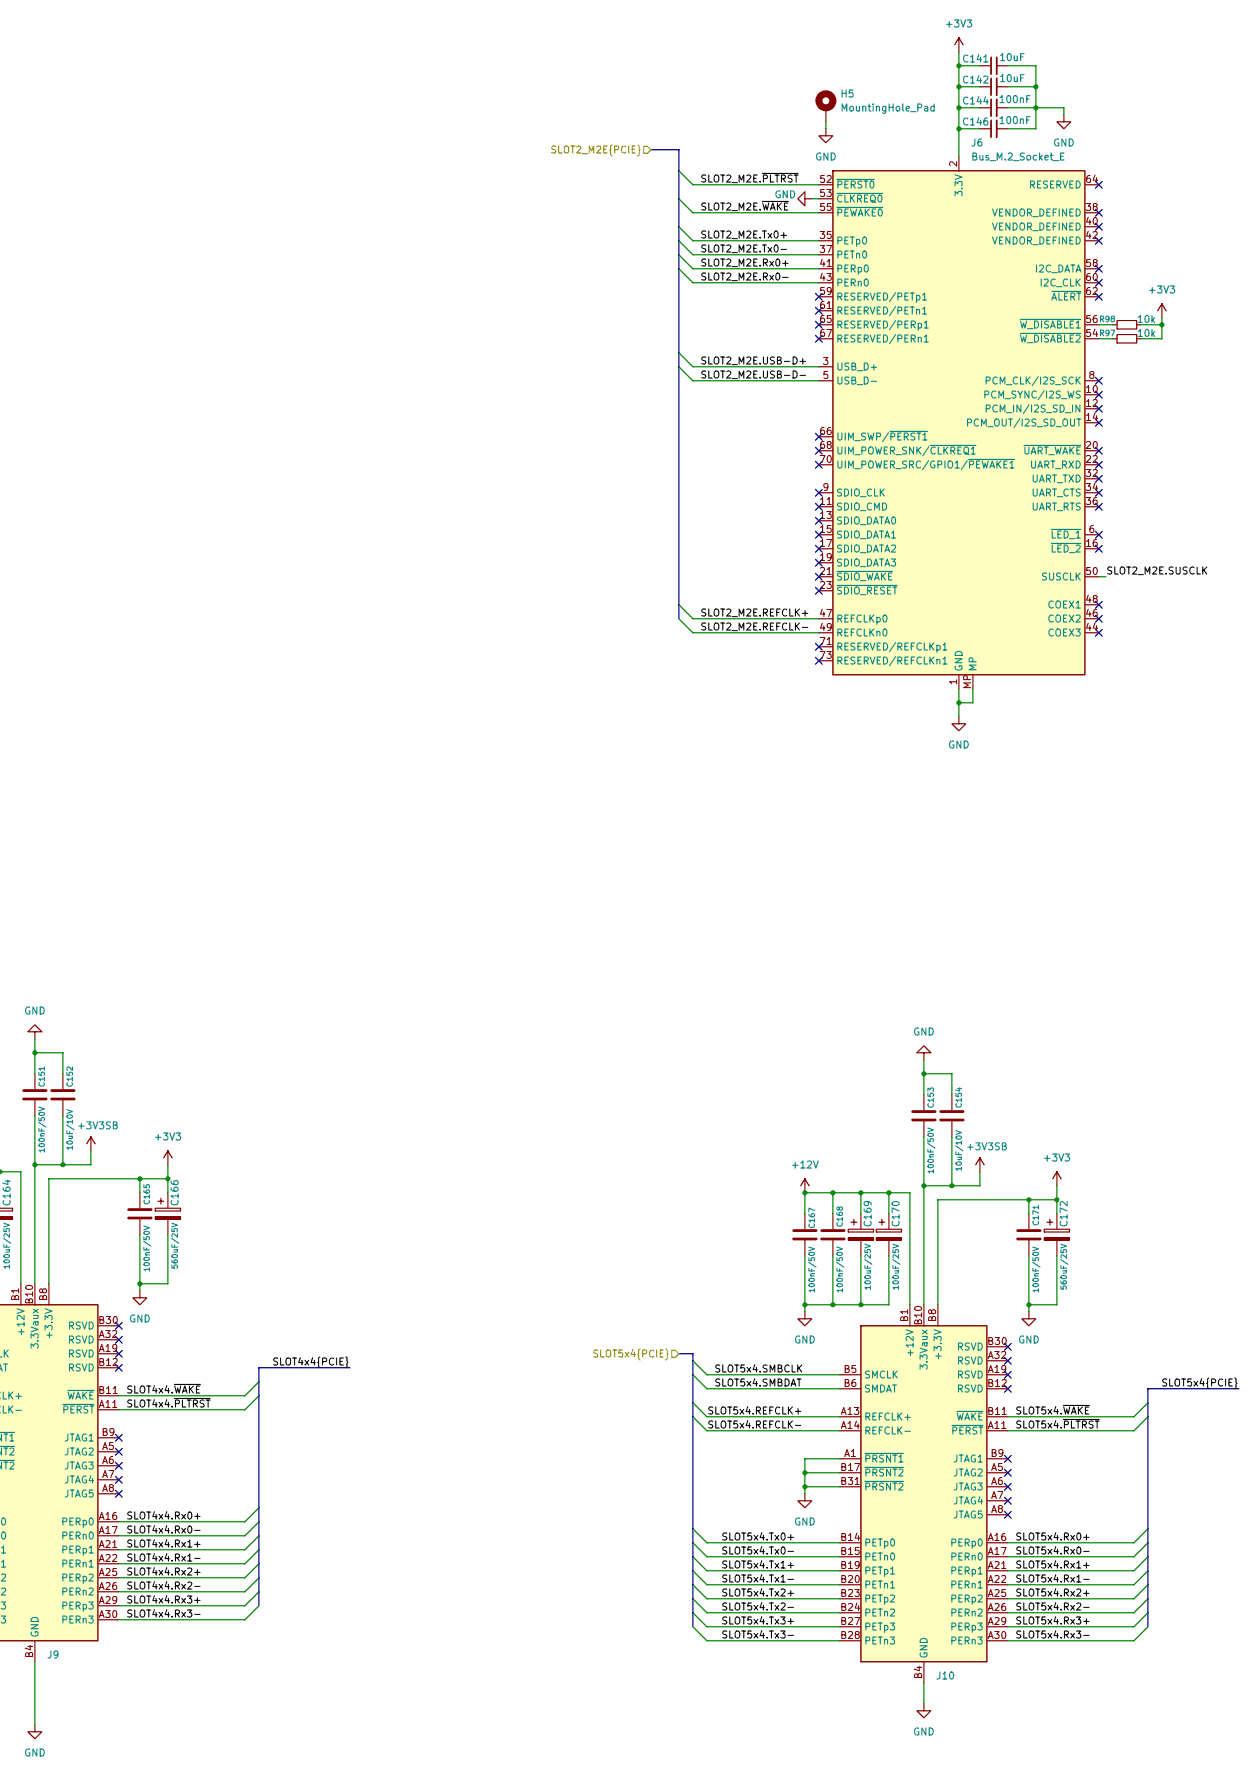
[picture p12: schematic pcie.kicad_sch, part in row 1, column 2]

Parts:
C141, C142, C143, C145: 10uF; C_0603_1608Metric
C144, C146, C147, C148: 100nF; C_0402_1005Metric
C149, C151, C153, C155, C156, C159, C161, C162, C165, C167, C168, C171: 100nF/50V; C_0402_1005Metric
C150, C152, C154: 10uF/10V; C_0603_1608Metric
C157, C158, C163, C164, C169, C170: 100uF/25V; CP_Elec_6.3x7.7
C160, C166, C172: 560uF/25V; CP_Elec_6.3x7.7
H5, H6: MountingHole_Pad; MountingHole_2.2mm_M2_Pad_Via
J6, J7: Bus_M.2_Socket_E; CONN-SMD_AS0BC21-S48BE-7H
J8: Bus_PCI_Express_x1; CONN-TH_HYCW05-PCI36-155B
J9, J10: Bus_PCI_Express_x4; PCIE-TH_AAA-PCI-161-K03
R97, R98, R99, R100: 10k; R_0402_1005Metric

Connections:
+3V3: C141.1, C142.1, C143.1, C144.1, C145.1, C146.1, C147.1, C148.1, C159.1, C160.1, C165.1, C166.1, C171.1, C172.1, J6.2 (3.3V), J6.4 (3.3V), J6.72 (3.3V), J6.74 (3.3V), J7.2 (3.3V), J7.4 (3.3V), J7.72 (3.3V), J7.74 (3.3V), J8.A9 (+3.3V), J8.A10 (+3.3V), J8.B8 (+3.3V), J9.A9 (+3.3V), J9.A10 (+3.3V), J9.B8 (+3.3V), J10.A9 (+3.3V), J10.A10 (+3.3V), J10.B8 (+3.3V), R97.2, R98.2, R99.2, R100.2; also elsewhere on the board
+3V3SB: C149.2, C150.2, C151.2, C152.2, C153.2, C154.2, J8.B10 (3.3Vaux), J9.B10 (3.3Vaux), J10.B10 (3.3Vaux); also elsewhere on the board
+12V: C155.1, C156.1, C157.1, C158.1, C161.1, C162.1, C163.1, C164.1, C167.1, C168.1, C169.1, C170.1, J8.A2 (+12V), J8.A3 (+12V), J8.B1 (+12V), J8.B2 (+12V), J8.B3 (+12V), J9.A2 (+12V), J9.A3 (+12V), J9.B1 (+12V), J9.B2 (+12V), J9.B3 (+12V), J10.A2 (+12V), J10.A3 (+12V), J10.B1 (+12V), J10.B2 (+12V), J10.B3 (+12V); also elsewhere on the board
/Module 1/M2_EKEY.REFCLK+: J7.47 (REFCLKp0); also elsewhere on the board
/Module 1/M2_EKEY.REFCLK-: J7.49 (REFCLKn0); also elsewhere on the board
/Module 1/M2_EKEY.Rx0+: J7.41 (PERp0); also elsewhere on the board
/Module 1/M2_EKEY.Rx0-: J7.43 (PERn0); also elsewhere on the board
/Module 1/M2_EKEY.SUSCLK: J7.50 (SUSCLK)
/Module 1/M2_EKEY.Tx0+: J7.35 (PETp0); also elsewhere on the board
/Module 1/M2_EKEY.Tx0-: J7.37 (PETn0); also elsewhere on the board
/Module 1/M2_EKEY.USB-D+: J7.3 (USB_D+)
/Module 1/M2_EKEY.USB-D-: J7.5 (USB_D-)
/Module 1/NVME.~PLTRST: J7.52 (~PERST0); also elsewhere on the board
/Module 1/NVME.~WAKE: J7.55 (~PEWAKE0); also elsewhere on the board
/Module 2/M2_EKEY.REFCLK+: J6.47 (REFCLKp0); also elsewhere on the board
/Module 2/M2_EKEY.REFCLK-: J6.49 (REFCLKn0); also elsewhere on the board
/Module 2/M2_EKEY.Rx0+: J6.41 (PERp0); also elsewhere on the board
/Module 2/M2_EKEY.Rx0-: J6.43 (PERn0); also elsewhere on the board
/Module 2/M2_EKEY.Tx0+: J6.35 (PETp0); also elsewhere on the board
/Module 2/M2_EKEY.Tx0-: J6.37 (PETn0); also elsewhere on the board
/Module 2/M2_EKEY.USB-D+: J6.3 (USB_D+); also elsewhere on the board
/Module 2/M2_EKEY.USB-D-: J6.5 (USB_D-); also elsewhere on the board
/Module 2/NVME.SUSCLK: J6.50 (SUSCLK); also elsewhere on the board
/Module 2/NVME.~PLTRST: J6.52 (~PERST0); also elsewhere on the board
/Module 2/NVME.~WAKE: J6.55 (~PEWAKE0); also elsewhere on the board
/Module 3/NVME.~PLTRST: J8.A11 (~PERST); also elsewhere on the board
/Module 3/NVME.~WAKE: J8.B11 (~WAKE); also elsewhere on the board
/Module 3/PCIE_X1.REFCLK+: J8.A13 (REFCLK+); also elsewhere on the board
/Module 3/PCIE_X1.REFCLK-: J8.A14 (REFCLK-); also elsewhere on the board
/Module 3/PCIE_X1.Rx0+: J8.A16 (PERp0); also elsewhere on the board
/Module 3/PCIE_X1.Rx0-: J8.A17 (PERn0); also elsewhere on the board
/Module 3/PCIE_X1.SMBCLK: J8.B5 (SMCLK)
/Module 3/PCIE_X1.SMBDAT: J8.B6 (SMDAT)
/Module 3/PCIE_X1.Tx0+: J8.B14 (PETp0); also elsewhere on the board
/Module 3/PCIE_X1.Tx0-: J8.B15 (PETn0); also elsewhere on the board
/Module 4/NVME.~PLTRST: J9.A11 (~PERST); also elsewhere on the board
/Module 4/NVME.~WAKE: J9.B11 (~WAKE); also elsewhere on the board
/Module 4/PCIE_X4.REFCLK+: J9.A13 (REFCLK+); also elsewhere on the board
/Module 4/PCIE_X4.REFCLK-: J9.A14 (REFCLK-); also elsewhere on the board
/Module 4/PCIE_X4.Rx0+: J9.A16 (PERp0); also elsewhere on the board
/Module 4/PCIE_X4.Rx0-: J9.A17 (PERn0); also elsewhere on the board
/Module 4/PCIE_X4.Rx1+: J9.A21 (PERp1)
/Module 4/PCIE_X4.Rx1-: J9.A22 (PERn1)
/Module 4/PCIE_X4.Rx2+: J9.A25 (PERp2); also elsewhere on the board
/Module 4/PCIE_X4.Rx2-: J9.A26 (PERn2); also elsewhere on the board
/Module 4/PCIE_X4.Rx3+: J9.A29 (PERp3); also elsewhere on the board
/Module 4/PCIE_X4.Rx3-: J9.A30 (PERn3); also elsewhere on the board
/Module 4/PCIE_X4.SMBCLK: J9.B5 (SMCLK); also elsewhere on the board
/Module 4/PCIE_X4.SMBDAT: J9.B6 (SMDAT); also elsewhere on the board
/Module 4/PCIE_X4.Tx0+: J9.B14 (PETp0); also elsewhere on the board
/Module 4/PCIE_X4.Tx0-: J9.B15 (PETn0); also elsewhere on the board
/Module 4/PCIE_X4.Tx1+: J9.B19 (PETp1)
/Module 4/PCIE_X4.Tx1-: J9.B20 (PETn1)
/Module 4/PCIE_X4.Tx2+: J9.B23 (PETp2); also elsewhere on the board
/Module 4/PCIE_X4.Tx2-: J9.B24 (PETn2); also elsewhere on the board
/Module 4/PCIE_X4.Tx3+: J9.B27 (PETp3); also elsewhere on the board
/Module 4/PCIE_X4.Tx3-: J9.B28 (PETn3); also elsewhere on the board
/Module 5/NVME.~PLTRST: J10.A11 (~PERST); also elsewhere on the board
/Module 5/NVME.~WAKE: J10.B11 (~WAKE); also elsewhere on the board
/Module 5/PCIE_X4.REFCLK+: J10.A13 (REFCLK+); also elsewhere on the board
/Module 5/PCIE_X4.REFCLK-: J10.A14 (REFCLK-); also elsewhere on the board
/Module 5/PCIE_X4.Rx0+: J10.A16 (PERp0); also elsewhere on the board
/Module 5/PCIE_X4.Rx0-: J10.A17 (PERn0); also elsewhere on the board
/Module 5/PCIE_X4.Rx1+: J10.A21 (PERp1); also elsewhere on the board
/Module 5/PCIE_X4.Rx1-: J10.A22 (PERn1); also elsewhere on the board
/Module 5/PCIE_X4.Rx2+: J10.A25 (PERp2); also elsewhere on the board
/Module 5/PCIE_X4.Rx2-: J10.A26 (PERn2); also elsewhere on the board
/Module 5/PCIE_X4.Rx3+: J10.A29 (PERp3); also elsewhere on the board
/Module 5/PCIE_X4.Rx3-: J10.A30 (PERn3); also elsewhere on the board
/Module 5/PCIE_X4.SMBCLK: J10.B5 (SMCLK); also elsewhere on the board
/Module 5/PCIE_X4.SMBDAT: J10.B6 (SMDAT); also elsewhere on the board
/Module 5/PCIE_X4.Tx0+: J10.B14 (PETp0); also elsewhere on the board
/Module 5/PCIE_X4.Tx0-: J10.B15 (PETn0); also elsewhere on the board
/Module 5/PCIE_X4.Tx1+: J10.B19 (PETp1); also elsewhere on the board
/Module 5/PCIE_X4.Tx1-: J10.B20 (PETn1); also elsewhere on the board
/Module 5/PCIE_X4.Tx2+: J10.B23 (PETp2); also elsewhere on the board
/Module 5/PCIE_X4.Tx2-: J10.B24 (PETn2); also elsewhere on the board
/Module 5/PCIE_X4.Tx3+: J10.B27 (PETp3); also elsewhere on the board
/Module 5/PCIE_X4.Tx3-: J10.B28 (PETn3); also elsewhere on the board
unnamed: J6.56 (~W_DISABLE1), R97.1
unnamed: J6.54 (~W_DISABLE2), R98.1
unnamed: J7.56 (~W_DISABLE1), R99.1
unnamed: J7.54 (~W_DISABLE2), R100.1

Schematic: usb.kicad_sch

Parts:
J19: RJE361882415; AMPHENOL_RJE361882415
J21: USB3_A_Stacked; USB-A-TH_HC-USB3.0-L175-2X1-J
J22: USB3_IDC; IDC-Header_2x10_P2.54mm_Vertical
J23: Conn_02x05_Odd_Even; PinHeader_2x05_P2.54mm_Vertical
U28, U29, U30, U31, U32, U33, U34, U35, U36, U37: H5VU25U; Diodes_UDFN-10_1.0x2.5mm_P0.5mm

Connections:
+5VSB: J19.U1 (VBUS), J19.U10 (VBUS), J21.1 (VBUS1), J21.10 (VBUS2), J22.1 (VBUS1), J22.11 (VBUS2), J23.1, J23.2; also elsewhere on the board
/Module 1/RUSB_1.D+: J19.U3 (D+), U28.2; also elsewhere on the board
/Module 1/RUSB_1.D-: J19.U2 (D-), U28.1; also elsewhere on the board
/Module 1/RUSB_1.SS_Rx1+: J19.U6 (SSRX+), U30.4; also elsewhere on the board
/Module 1/RUSB_1.SS_Rx1-: J19.U5 (SSRX-), U30.2; also elsewhere on the board
/Module 1/RUSB_1.SS_Tx1+: J19.U9 (SSTX+), U30.5; also elsewhere on the board
/Module 1/RUSB_1.SS_Tx1-: J19.U8 (SSTX-), U30.1; also elsewhere on the board
/Module 1/RUSB_2.D+: J19.U12 (D+), U28.4; also elsewhere on the board
/Module 1/RUSB_2.D-: J19.U11 (D-), U28.5; also elsewhere on the board
/Module 1/RUSB_2.SS_Rx1+: J19.U15 (SSRX+), U29.4; also elsewhere on the board
/Module 1/RUSB_2.SS_Rx1-: J19.U14 (SSRX-), U29.2; also elsewhere on the board
/Module 1/RUSB_2.SS_Tx1+: J19.U18 (SSTX+), U29.5; also elsewhere on the board
/Module 1/RUSB_2.SS_Tx1-: J19.U17 (SSTX-), U29.1; also elsewhere on the board
/Module 2/FUSB.D+: J22.3 (D1+), U34.2; also elsewhere on the board
/Module 2/FUSB.D-: J22.2 (D1-), U34.1; also elsewhere on the board
/Module 2/FUSB.SS_Rx1+: J22.6 (SSRX1+), U36.4; also elsewhere on the board
/Module 2/FUSB.SS_Rx1-: J22.5 (SSRX1-), U36.2; also elsewhere on the board
/Module 2/FUSB.SS_Tx1+: J22.9 (SSTX1+), U36.5; also elsewhere on the board
/Module 2/FUSB.SS_Tx1-: J22.8 (SSTX1-), U36.1; also elsewhere on the board
/Module 2/RUSB.D+: J21.3 (D1+), U31.2; also elsewhere on the board
/Module 2/RUSB.D-: J21.2 (D1-), U31.1; also elsewhere on the board
/Module 2/RUSB.SS_Rx1+: J21.6 (SSRX1+), U33.4; also elsewhere on the board
/Module 2/RUSB.SS_Rx1-: J21.5 (SSRX1-), U33.2; also elsewhere on the board
/Module 2/RUSB.SS_Tx1+: J21.9 (SSTX1+), U33.5; also elsewhere on the board
/Module 2/RUSB.SS_Tx1-: J21.8 (SSTX1-), U33.1; also elsewhere on the board
/Module 3/FUSB.D+: J22.13 (D2+), U34.4; also elsewhere on the board
/Module 3/FUSB.D-: J22.12 (D2-), U34.5; also elsewhere on the board
/Module 3/FUSB.SS_Rx1+: J22.16 (SSRX2+), U35.4; also elsewhere on the board
/Module 3/FUSB.SS_Rx1-: J22.15 (SSRX2-), U35.2; also elsewhere on the board
/Module 3/FUSB.SS_Tx1+: J22.19 (SSTX2+), U35.5; also elsewhere on the board
/Module 3/FUSB.SS_Tx1-: J22.18 (SSTX2-), U35.1; also elsewhere on the board
/Module 3/RUSB.D+: J21.12 (D2+), U31.4; also elsewhere on the board
/Module 3/RUSB.D-: J21.11 (D2-), U31.5; also elsewhere on the board
/Module 3/RUSB.SS_Rx1+: J21.15 (SSRX2+), U32.4; also elsewhere on the board
/Module 3/RUSB.SS_Rx1-: J21.14 (SSRX2-), U32.2; also elsewhere on the board
/Module 3/RUSB.SS_Tx1+: J21.18 (SSTX2+), U32.5; also elsewhere on the board
/Module 3/RUSB.SS_Tx1-: J21.17 (SSTX2-), U32.1; also elsewhere on the board
/Module 4/FUSB_D+: J23.5, U37.5; also elsewhere on the board
/Module 4/FUSB_D-: J23.3, U37.4; also elsewhere on the board
/Module 5/FUSB_D+: J23.6, U37.2; also elsewhere on the board
/Module 5/FUSB_D-: J23.4, U37.1; also elsewhere on the board

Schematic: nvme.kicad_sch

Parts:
C173, C174, C175, C176, C177, C178, C185, C186, C187, C188: 10uF; C_0603_1608Metric
C179, C180, C181, C182, C183, C184, C189, C190, C191, C192: 100nF; C_0402_1005Metric
D22, D23, D24, D25, D26: LED; LED_0603_1608Metric
H7, H8, H9, H10, H11: MountingHole_Pad; MountingHole_2.2mm_M2_Pad_Via
J11, J12, J13, J14, J15: Bus_M.2_Socket_M; CONN-SMD_AS0BC21-S30BM-7H
R101, R102, R103, R104, R105: 2.2k; R_0402_1005Metric

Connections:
+3V3: C173.1, C174.1, C175.1, C176.1, C177.1, C178.1, C179.1, C180.1, C181.1, C182.1, C183.1, C184.1, C185.1, C186.1, C187.1, C188.1, C189.1, C190.1, C191.1, C192.1, J11.2 (3.3V), J11.4 (3.3V), J11.12 (3.3V), J11.14 (3.3V), J11.16 (3.3V), J11.18 (3.3V), J11.70 (3.3V), J11.72 (3.3V), J11.74 (3.3V), J12.2 (3.3V), J12.4 (3.3V), J12.12 (3.3V), J12.14 (3.3V), J12.16 (3.3V), J12.18 (3.3V), J12.70 (3.3V), J12.72 (3.3V), J12.74 (3.3V), J13.2 (3.3V), J13.4 (3.3V), J13.12 (3.3V), J13.14 (3.3V), J13.16 (3.3V), J13.18 (3.3V), J13.70 (3.3V), J13.72 (3.3V), J13.74 (3.3V), J14.2 (3.3V), J14.4 (3.3V), J14.12 (3.3V), J14.14 (3.3V), J14.16 (3.3V), J14.18 (3.3V), J14.70 (3.3V), J14.72 (3.3V), J14.74 (3.3V), J15.2 (3.3V), J15.4 (3.3V), J15.12 (3.3V), J15.14 (3.3V), J15.16 (3.3V), J15.18 (3.3V), J15.70 (3.3V), J15.72 (3.3V), J15.74 (3.3V), R101.2, R102.2, R103.2, R104.2, R105.2; also elsewhere on the board
/Module 1/NVME.REFCLK+: J11.55 (REFCLKp); also elsewhere on the board
/Module 1/NVME.REFCLK-: J11.53 (REFCLKn); also elsewhere on the board
/Module 1/NVME.Rx0+: J11.43 (PERp0/SATA-B-); also elsewhere on the board
/Module 1/NVME.Rx0-: J11.41 (PERn0/SATA-B+); also elsewhere on the board
/Module 1/NVME.Rx1+: J11.31 (PERp1); also elsewhere on the board
/Module 1/NVME.Rx1-: J11.29 (PERn1); also elsewhere on the board
/Module 1/NVME.SUSCLK: J11.68 (SUSCLK); also elsewhere on the board
/Module 1/NVME.Tx0+: J11.49 (PETp0/SATA-A+); also elsewhere on the board
/Module 1/NVME.Tx0-: J11.47 (PETn0/SATA-A-); also elsewhere on the board
/Module 1/NVME.Tx1+: J11.37 (PETp1); also elsewhere on the board
/Module 1/NVME.Tx1-: J11.35 (PETn1); also elsewhere on the board
/Module 1/NVME.~PLTRST: J11.50 (~PERST); also elsewhere on the board
/Module 1/NVME.~WAKE: J11.54 (~PEWAKE); also elsewhere on the board
/Module 2/NVME.REFCLK+: J12.55 (REFCLKp); also elsewhere on the board
/Module 2/NVME.REFCLK-: J12.53 (REFCLKn); also elsewhere on the board
/Module 2/NVME.Rx0+: J12.43 (PERp0/SATA-B-); also elsewhere on the board
/Module 2/NVME.Rx0-: J12.41 (PERn0/SATA-B+); also elsewhere on the board
/Module 2/NVME.Rx1+: J12.31 (PERp1); also elsewhere on the board
/Module 2/NVME.Rx1-: J12.29 (PERn1); also elsewhere on the board
/Module 2/NVME.SUSCLK: J12.68 (SUSCLK); also elsewhere on the board
/Module 2/NVME.Tx0+: J12.49 (PETp0/SATA-A+); also elsewhere on the board
/Module 2/NVME.Tx0-: J12.47 (PETn0/SATA-A-); also elsewhere on the board
/Module 2/NVME.Tx1+: J12.37 (PETp1); also elsewhere on the board
/Module 2/NVME.Tx1-: J12.35 (PETn1); also elsewhere on the board
/Module 2/NVME.~PLTRST: J12.50 (~PERST); also elsewhere on the board
/Module 2/NVME.~WAKE: J12.54 (~PEWAKE); also elsewhere on the board
/Module 3/NVME.REFCLK+: J13.55 (REFCLKp); also elsewhere on the board
/Module 3/NVME.REFCLK-: J13.53 (REFCLKn); also elsewhere on the board
/Module 3/NVME.Rx0+: J13.43 (PERp0/SATA-B-); also elsewhere on the board
/Module 3/NVME.Rx0-: J13.41 (PERn0/SATA-B+); also elsewhere on the board
/Module 3/NVME.Rx1+: J13.31 (PERp1); also elsewhere on the board
/Module 3/NVME.Rx1-: J13.29 (PERn1); also elsewhere on the board
/Module 3/NVME.SUSCLK: J13.68 (SUSCLK); also elsewhere on the board
/Module 3/NVME.Tx0+: J13.49 (PETp0/SATA-A+); also elsewhere on the board
/Module 3/NVME.Tx0-: J13.47 (PETn0/SATA-A-); also elsewhere on the board
/Module 3/NVME.Tx1+: J13.37 (PETp1); also elsewhere on the board
/Module 3/NVME.Tx1-: J13.35 (PETn1); also elsewhere on the board
/Module 3/NVME.~PLTRST: J13.50 (~PERST); also elsewhere on the board
/Module 3/NVME.~WAKE: J13.54 (~PEWAKE); also elsewhere on the board
/Module 4/NVME.REFCLK+: J15.55 (REFCLKp); also elsewhere on the board
/Module 4/NVME.REFCLK-: J15.53 (REFCLKn); also elsewhere on the board
/Module 4/NVME.Rx0+: J15.43 (PERp0/SATA-B-); also elsewhere on the board
/Module 4/NVME.Rx0-: J15.41 (PERn0/SATA-B+); also elsewhere on the board
/Module 4/NVME.Rx1+: J15.31 (PERp1)
/Module 4/NVME.Rx1-: J15.29 (PERn1)
/Module 4/NVME.SUSCLK: J15.68 (SUSCLK); also elsewhere on the board
/Module 4/NVME.Tx0+: J15.49 (PETp0/SATA-A+); also elsewhere on the board
/Module 4/NVME.Tx0-: J15.47 (PETn0/SATA-A-); also elsewhere on the board
/Module 4/NVME.Tx1+: J15.37 (PETp1)
/Module 4/NVME.Tx1-: J15.35 (PETn1)
/Module 4/NVME.~PLTRST: J15.50 (~PERST); also elsewhere on the board
/Module 4/NVME.~WAKE: J15.54 (~PEWAKE); also elsewhere on the board
/Module 5/NVME.REFCLK+: J14.55 (REFCLKp); also elsewhere on the board
/Module 5/NVME.REFCLK-: J14.53 (REFCLKn); also elsewhere on the board
/Module 5/NVME.Rx0+: J14.43 (PERp0/SATA-B-); also elsewhere on the board
/Module 5/NVME.Rx0-: J14.41 (PERn0/SATA-B+); also elsewhere on the board
/Module 5/NVME.Rx1+: J14.31 (PERp1); also elsewhere on the board
/Module 5/NVME.Rx1-: J14.29 (PERn1); also elsewhere on the board
/Module 5/NVME.SUSCLK: J14.68 (SUSCLK); also elsewhere on the board
/Module 5/NVME.Tx0+: J14.49 (PETp0/SATA-A+); also elsewhere on the board
/Module 5/NVME.Tx0-: J14.47 (PETn0/SATA-A-); also elsewhere on the board
/Module 5/NVME.Tx1+: J14.37 (PETp1); also elsewhere on the board
/Module 5/NVME.Tx1-: J14.35 (PETn1); also elsewhere on the board
/Module 5/NVME.~PLTRST: J14.50 (~PERST); also elsewhere on the board
/Module 5/NVME.~WAKE: J14.54 (~PEWAKE); also elsewhere on the board
unnamed: D22.2 (A), R101.1
unnamed: D22.1 (K), J11.10 (DAS/~DSS/~LED1)
unnamed: D23.2 (A), R102.1
unnamed: D23.1 (K), J12.10 (DAS/~DSS/~LED1)
unnamed: D24.2 (A), R103.1
unnamed: D24.1 (K), J13.10 (DAS/~DSS/~LED1)
unnamed: D25.2 (A), R104.1
unnamed: D25.1 (K), J14.10 (DAS/~DSS/~LED1)
unnamed: D26.2 (A), R105.1
unnamed: D26.1 (K), J15.10 (DAS/~DSS/~LED1)

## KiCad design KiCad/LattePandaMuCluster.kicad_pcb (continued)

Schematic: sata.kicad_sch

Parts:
J3, J4: SFF-8087; CONN-SMD_LD2136V-MCUL6
J5: SATA; CONN-TH_XUTS-0722-2070

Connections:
/Module 1/SATA1.Rx+: J3.A2 (Rx0+); also elsewhere on the board
/Module 1/SATA1.Rx-: J3.A3 (Rx0-); also elsewhere on the board
/Module 1/SATA1.Tx+: J3.B2 (Tx0+); also elsewhere on the board
/Module 1/SATA1.Tx-: J3.B3 (Tx0-); also elsewhere on the board
/Module 1/SATA2.Rx+: J4.A2 (Rx0+); also elsewhere on the board
/Module 1/SATA2.Rx-: J4.A3 (Rx0-); also elsewhere on the board
/Module 1/SATA2.Tx+: J4.B2 (Tx0+); also elsewhere on the board
/Module 1/SATA2.Tx-: J4.B3 (Tx0-); also elsewhere on the board
/Module 2/SATA1.Rx+: J3.A5 (Rx1+); also elsewhere on the board
/Module 2/SATA1.Rx-: J3.A6 (Rx1-); also elsewhere on the board
/Module 2/SATA1.Tx+: J3.B5 (Tx1+); also elsewhere on the board
/Module 2/SATA1.Tx-: J3.B6 (Tx1-); also elsewhere on the board
/Module 2/SATA2.Rx+: J4.A5 (Rx1+); also elsewhere on the board
/Module 2/SATA2.Rx-: J4.A6 (Rx1-); also elsewhere on the board
/Module 2/SATA2.Tx+: J4.B5 (Tx1+); also elsewhere on the board
/Module 2/SATA2.Tx-: J4.B6 (Tx1-); also elsewhere on the board
/Module 3/SATA1.Rx+: J3.A13 (Rx2+); also elsewhere on the board
/Module 3/SATA1.Rx-: J3.A14 (Rx2-); also elsewhere on the board
/Module 3/SATA1.Tx+: J3.B13 (Tx2+); also elsewhere on the board
/Module 3/SATA1.Tx-: J3.B14 (Tx2-); also elsewhere on the board
/Module 3/SATA2.Rx+: J4.A13 (Rx2+); also elsewhere on the board
/Module 3/SATA2.Rx-: J4.A14 (Rx2-); also elsewhere on the board
/Module 3/SATA2.Tx+: J4.B13 (Tx2+); also elsewhere on the board
/Module 3/SATA2.Tx-: J4.B14 (Tx2-); also elsewhere on the board
/Module 4/SATA1.Rx+: J3.A16 (Rx3+); also elsewhere on the board
/Module 4/SATA1.Rx-: J3.A17 (Rx3-); also elsewhere on the board
/Module 4/SATA1.Tx+: J3.B16 (Tx3+); also elsewhere on the board
/Module 4/SATA1.Tx-: J3.B17 (Tx3-); also elsewhere on the board
/Module 4/SATA2.Rx+: J4.A16 (Rx3+); also elsewhere on the board
/Module 4/SATA2.Rx-: J4.A17 (Rx3-); also elsewhere on the board
/Module 4/SATA2.Tx+: J4.B16 (Tx3+); also elsewhere on the board
/Module 4/SATA2.Tx-: J4.B17 (Tx3-); also elsewhere on the board
/Module 5/SATA1.Rx+: J5.6 (Rx+); also elsewhere on the board
/Module 5/SATA1.Rx-: J5.5 (Rx-); also elsewhere on the board
/Module 5/SATA1.Tx+: J5.2 (Tx+); also elsewhere on the board
/Module 5/SATA1.Tx-: J5.3 (Tx-); also elsewhere on the board
/Module 5/SATA2.Rx+: J5.S6 (Rx+); also elsewhere on the board
/Module 5/SATA2.Rx-: J5.S5 (Rx-); also elsewhere on the board
/Module 5/SATA2.Tx+: J5.S2 (Tx+); also elsewhere on the board
/Module 5/SATA2.Tx-: J5.S3 (Tx-); also elsewhere on the board

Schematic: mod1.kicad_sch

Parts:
A1: LattePanda_Mu; ATTEND_124B-150A02
C1, C2, C3, C4, C5, C6, C23, C26, C27: 100nF; C_0402_1005Metric
C7, C8, C9, C10, C11, C12, C21, C22, C30, C31, C34, C35: 220nF; C_0402_1005Metric
C13, C14, C15, C16, C17, C18, C19, C20: 10nF; C_0402_1005Metric
C24, C25: 100pF; C_0402_1005Metric
C28, C29, C32, C33: 330nF; C_0402_1005Metric
D1, D2: B0520W; D_SOD-123
D3, D4: LED; LED_0603_1608Metric
M1: Fan_4pin; JST_PH_B4B-PH-K_1x04_P2.00mm_Vertical
M2: Fan_4pin; FanPinHeader_1x04_P2.54mm_Vertical
R1, R2: 4.7k; R_0402_1005Metric
R3, R4, R7: 22k; R_0402_1005Metric
R5, R6, R10, R11, R13, R14, R15, R16, R17, R18: 100R; R_0402_1005Metric
R8: 1k; R_0805_2012Metric
R9, R12: 2.2k; R_0402_1005Metric
R19, R20, R22: 10k; R_0402_1005Metric
R21, R23, R24: 100k; R_0402_1005Metric
U1: ZD25Q64BSIGT; SOIC-8_5.3x5.3mm_P1.27mm

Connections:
+3V3: C23.1, R9.1, R12.2, R19.1, R20.1, U1.8 (VCC); also elsewhere on the board
+5V: C1.1, D1.1 (K), M1.2 (+), R1.1; also elsewhere on the board
+12V: C2.1, D2.1 (K), M2.2 (+), R2.1; also elsewhere on the board
+12VCPU: A1.250 (VIN), A1.251 (VIN), A1.252 (VIN), A1.253 (VIN), A1.254 (VIN), A1.255 (VIN), A1.256 (VIN), A1.257 (VIN), A1.258 (VIN), A1.259 (VIN), A1.260 (VIN); also elsewhere on the board
+BATT: R8.1; also elsewhere on the board
/HDMI/SLOT1_HDMI.HPD: A1.183 (DDIB_HPD); also elsewhere on the board
/HDMI/SLOT1_HDMI.SCL: A1.171 (DDIB_DDC_SCL); also elsewhere on the board
/HDMI/SLOT1_HDMI.SDA: A1.169 (DDIB_DDC_SDA); also elsewhere on the board
/HDMI/SLOT1_HDMI.Tx0+: A1.217 (DDIB_TX0+); also elsewhere on the board
/HDMI/SLOT1_HDMI.Tx0-: A1.215 (DDIB_TX0-); also elsewhere on the board
/HDMI/SLOT1_HDMI.Tx1+: A1.211 (DDIB_TX1+); also elsewhere on the board
/HDMI/SLOT1_HDMI.Tx1-: A1.209 (DDIB_TX1-); also elsewhere on the board
/HDMI/SLOT1_HDMI.Tx2+: A1.205 (DDIB_TX2+); also elsewhere on the board
/HDMI/SLOT1_HDMI.Tx2-: A1.203 (DDIB_TX2-); also elsewhere on the board
/HDMI/SLOT1_HDMI.Tx3+: A1.199 (DDIB_TX3+); also elsewhere on the board
/HDMI/SLOT1_HDMI.Tx3-: A1.197 (DDIB_TX3-); also elsewhere on the board
/Module 1/ETH.REFCLK+: A1.88 (REFCLK3+); also elsewhere on the board
/Module 1/ETH.REFCLK-: A1.90 (REFCLK3-); also elsewhere on the board
/Module 1/ETH.Rx0+: A1.64 (HSIO6_RX+); also elsewhere on the board
/Module 1/ETH.Rx0-: A1.66 (HSIO6_RX-); also elsewhere on the board
/Module 1/ETH.SMBCLK: A1.106 (SMB_CLK); also elsewhere on the board
/Module 1/ETH.SMBDAT: A1.108 (SMB_DATA); also elsewhere on the board
/Module 1/ETH.Tx0+: C21.1; also elsewhere on the board
/Module 1/ETH.Tx0-: C22.1; also elsewhere on the board
/Module 1/ETH.~CLKREQ: A1.100 (~CLKREQ3); also elsewhere on the board
/Module 1/HDD_LED: A1.123 (GPP_B14), D4.1 (K); also elsewhere on the board
/Module 1/M2_EKEY.REFCLK+: A1.94 (REFCLK4+); also elsewhere on the board
/Module 1/M2_EKEY.REFCLK-: A1.96 (REFCLK4-); also elsewhere on the board
/Module 1/M2_EKEY.Rx0+: A1.28 (HSIO2_RX+); also elsewhere on the board
/Module 1/M2_EKEY.Rx0-: A1.30 (HSIO2_RX-); also elsewhere on the board
/Module 1/M2_EKEY.Tx0+: C7.1; also elsewhere on the board
/Module 1/M2_EKEY.Tx0-: C8.1; also elsewhere on the board
/Module 1/M2_EKEY.~CLKREQ: A1.102 (~CLKREQ4)
/Module 1/NVME.REFCLK+: A1.97 (REFCLK2+); also elsewhere on the board
/Module 1/NVME.REFCLK-: A1.99 (REFCLK2-); also elsewhere on the board
/Module 1/NVME.Rx0+: A1.40 (HSIO8_RX+); also elsewhere on the board
/Module 1/NVME.Rx0-: A1.42 (HSIO8_RX-); also elsewhere on the board
/Module 1/NVME.Rx1+: A1.46 (HSIO9_RX+); also elsewhere on the board
/Module 1/NVME.Rx1-: A1.48 (HSIO9_RX-); also elsewhere on the board
/Module 1/NVME.SUSCLK: A1.131 (SUSCLK); also elsewhere on the board
/Module 1/NVME.Tx0+: C9.1; also elsewhere on the board
/Module 1/NVME.Tx0-: C10.1; also elsewhere on the board
/Module 1/NVME.Tx1+: C11.1; also elsewhere on the board
/Module 1/NVME.Tx1-: C12.1; also elsewhere on the board
/Module 1/NVME.~PLTRST: A1.105 (~PLTRST); also elsewhere on the board
/Module 1/NVME.~WAKE: A1.103 (~WAKE); also elsewhere on the board
/Module 1/PGM_INT: A1.132 (GPP_D2); also elsewhere on the board
/Module 1/PGM_SCL: A1.154 (I2C2_SCL); also elsewhere on the board
/Module 1/PGM_SDA: A1.156 (I2C2_SDA); also elsewhere on the board
/Module 1/RUSB_1.D+: A1.69 (USB2_P1+); also elsewhere on the board
/Module 1/RUSB_1.D-: A1.67 (USB2_P1-); also elsewhere on the board
/Module 1/RUSB_1.SS_Rx1+: A1.16 (HSIO0_RX+); also elsewhere on the board
/Module 1/RUSB_1.SS_Rx1-: A1.18 (HSIO0_RX-); also elsewhere on the board
/Module 1/RUSB_1.SS_Tx1+: C3.1; also elsewhere on the board
/Module 1/RUSB_1.SS_Tx1-: C4.1; also elsewhere on the board
/Module 1/RUSB_2.D+: A1.75 (USB2_P2+); also elsewhere on the board
/Module 1/RUSB_2.D-: A1.73 (USB2_P2-); also elsewhere on the board
/Module 1/RUSB_2.SS_Rx1+: A1.22 (HSIO1_RX+); also elsewhere on the board
/Module 1/RUSB_2.SS_Rx1-: A1.24 (HSIO1_RX-); also elsewhere on the board
/Module 1/RUSB_2.SS_Tx1+: C5.1; also elsewhere on the board
/Module 1/RUSB_2.SS_Tx1-: C6.1; also elsewhere on the board
/Module 1/SATA1.Rx+: C15.1; also elsewhere on the board
/Module 1/SATA1.Rx-: C16.1; also elsewhere on the board
/Module 1/SATA1.Tx+: C13.1; also elsewhere on the board
/Module 1/SATA1.Tx-: C14.1; also elsewhere on the board
/Module 1/SATA2.Rx+: C19.1; also elsewhere on the board
/Module 1/SATA2.Rx-: C20.1; also elsewhere on the board
/Module 1/SATA2.Tx+: C17.1; also elsewhere on the board
/Module 1/SATA2.Tx-: C18.1; also elsewhere on the board
/Module 1/SLOT2_UART_RX: R11.1; also elsewhere on the board
/Module 1/SLOT2_UART_TX: R10.1; also elsewhere on the board
/Module 1/SLOT3_UART_TX: R14.2; also elsewhere on the board
/Module 1/SLOT4_UART_RX: R15.2; also elsewhere on the board
/Module 1/SLOT4_UART_TX: R16.2; also elsewhere on the board
/Module 1/SLOT5_UART_RX: R17.2; also elsewhere on the board
/Module 1/SLOT5_UART_TX: R18.2; also elsewhere on the board
/Module 1/TYPE_C_HEADER.D+: A1.112 (USB2_P6+); also elsewhere on the board
/Module 1/TYPE_C_HEADER.D-: A1.114 (USB2_P6-); also elsewhere on the board
/Module 1/TYPE_C_HEADER.SS_Rx1+: C32.1; also elsewhere on the board
/Module 1/TYPE_C_HEADER.SS_Rx1-: C33.1; also elsewhere on the board
/Module 1/TYPE_C_HEADER.SS_Rx2+: C28.1; also elsewhere on the board
/Module 1/TYPE_C_HEADER.SS_Rx2-: C29.1; also elsewhere on the board
/Module 1/TYPE_C_HEADER.SS_Tx1+: C34.1; also elsewhere on the board
/Module 1/TYPE_C_HEADER.SS_Tx1-: C35.1; also elsewhere on the board
/Module 1/TYPE_C_HEADER.SS_Tx2+: C30.1; also elsewhere on the board
/Module 1/TYPE_C_HEADER.SS_Tx2-: C31.1; also elsewhere on the board
/Module 1/TYPE_C_HPD: A1.185 (TCP1_HPD); also elsewhere on the board
/Module 1/TYPE_C_SCL: A1.147 (SML1_CLK); also elsewhere on the board
/Module 1/TYPE_C_SDA: A1.145 (SML1_DATA); also elsewhere on the board
/Module 1/~TYPE_C_PMCALERT: A1.125 (GPP_B11); also elsewhere on the board
/STM32/PWRBTN1: A1.1 (~PWRBTN); also elsewhere on the board
/STM32/PWRON1: A1.7 (SLS_S3); also elsewhere on the board
/STM32/RSTBTN1: A1.3 (~RSTBTN); also elsewhere on the board
unnamed: A1.2 (FAN1_PWM), R5.1
unnamed: A1.4 (FAN1_TAC), R3.1
unnamed: A1.6 (FAN2_PWM), R6.1
unnamed: A1.8 (FAN2_TAC), R4.1, R7.1
unnamed: A1.13 (HSIO0_TX+), C3.2
unnamed: A1.15 (HSIO0_TX-), C4.2
unnamed: A1.19 (HSIO1_TX+), C5.2
unnamed: A1.21 (HSIO1_TX-), C6.2
unnamed: A1.25 (HSIO2_TX+), C7.2
unnamed: A1.27 (HSIO2_TX-), C8.2
unnamed: A1.61 (HSIO6_TX+), C21.2
unnamed: A1.63 (HSIO6_TX-), C22.2
unnamed: A1.37 (HSIO8_TX+), C9.2
unnamed: A1.39 (HSIO8_TX-), C10.2
unnamed: A1.43 (HSIO9_TX+), C11.2
unnamed: A1.45 (HSIO9_TX-), C12.2
unnamed: A1.52 (HSIO10_RX+), C15.2
unnamed: A1.54 (HSIO10_RX-), C16.2
unnamed: A1.49 (HSIO10_TX+), C13.2
unnamed: A1.51 (HSIO10_TX-), C14.2
unnamed: A1.58 (HSIO11_RX+), C19.2
unnamed: A1.60 (HSIO11_RX-), C20.2
unnamed: A1.55 (HSIO11_TX+), C17.2
unnamed: A1.57 (HSIO11_TX-), C18.2
unnamed: A1.12 (SIO_UART_RX), R11.2
unnamed: A1.10 (SIO_UART_TX), R10.2
unnamed: A1.5 (SLS_S0), D3.1 (K)
unnamed: A1.155 (SPI_CLK), U1.6 (CLK)
unnamed: A1.161 (SPI_IO2), R20.2, U1.3 (~WP/IO_{2})
unnamed: A1.153 (SPI_IO3), R19.2, U1.7 (~HOLD/~RESET/IO_{3})
unnamed: A1.163 (SPI_MISO/SPI_IO1), U1.2 (DO/IO_{1})
unnamed: A1.159 (SPI_MOSI/SPI_IO0), U1.5 (DI/IO_{0})
unnamed: A1.187 (TCP0_HPD), R21.2
unnamed: A1.244 (TCP1_AUX+), C26.2
unnamed: A1.246 (TCP1_AUX-), C27.2
unnamed: A1.175 (TCP1_DDC_SCL), R24.2
unnamed: A1.173 (TCP1_DDC_SDA), R23.2
unnamed: A1.220 (TCP1_TX0+), C34.2
unnamed: A1.222 (TCP1_TX0-), C35.2
unnamed: A1.232 (TCP1_TX1+), C30.2
unnamed: A1.234 (TCP1_TX1-), C31.2
unnamed: A1.226 (TCP1_TXRX0+), C32.2
unnamed: A1.228 (TCP1_TXRX0-), C33.2
unnamed: A1.238 (TCP1_TXRX1+), C28.2
unnamed: A1.240 (TCP1_TXRX1-), C29.2
unnamed: A1.139 (UART0_TXD), R14.1
unnamed: A1.141 (UART1_RXD), R15.1
unnamed: A1.143 (UART1_TXD), R16.1
unnamed: A1.140 (UART2_RXD), R17.1
unnamed: A1.138 (UART2_TXD), R18.1
unnamed: A1.115 (VBAT), R8.2
unnamed: A1.133 (~BIOS_SEL), R22.1
unnamed: A1.165 (~SPI_CS), U1.1 (~CS)
unnamed: C25.2, R24.1
unnamed: D1.2 (A), M1.3 (Tacho), R1.2, R3.2
unnamed: D2.2 (A), M2.3 (Tacho), R2.2, R4.2
unnamed: D3.2 (A), R9.2
unnamed: D4.2 (A), R12.1
unnamed: M1.4 (PWM), R5.2
unnamed: M2.4 (PWM), R6.2

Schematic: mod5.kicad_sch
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

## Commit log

2025-08-23 Add programming header and power and reset switches
    [LattePandaMuCluster.kicad_sch, mod1.kicad_sch, psu.kicad_sch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]
2025-08-23 Connect PWR_ON and PWR_OK signals
    [LattePandaMuCluster.kicad_sch, stm32.kicad_sch]
2025-08-24 Add TPS65987D PD controller, switch stm32 to cheaper one
    [LattePandaMuCluster.kicad_sch, hdmi.kicad_sch, mod1.kicad_sch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]
2025-08-24 Connect TPS65987D I2C and Interrupts
    [LattePandaMuCluster.kicad_sch, mod1.kicad_sch, usbc.kicad_sch]
2025-08-25 Finish wiring TPS65987D
    [LattePandaMuCluster.kicad_sch, usbc.kicad_sch]
2025-08-25 Fix TPS65987D Symbol
    [usbc.kicad_sch]
2025-08-25 Clean up KiCad Backup Files From Git
2025-08-25 Missed a couple backup files
2025-08-25 Fix some diodes and resistors
    [hdmi.kicad_sch, mod1.kicad_sch, mod2.kicad_sch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]
2025-08-25 Add external BIOS flash
    [mod1.kicad_sch, mod2.kicad_sch, mod3.kicad_sch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]
2025-08-25 Switch nics to i226-v
    [eth.kicad_sch]
2025-08-26 Remove 0.95V Power Supply, Replace 3.3V Standby Power Supply
    [LattePandaMuCluster.kicad_sch, eth.kicad_sch, mod1.kicad_sch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]
2025-08-26 Work though ERC errors
    [eth.kicad_sch, mod1.kicad_sch, mod2.kicad_sch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]
2025-08-26 Re-annotate components
    [LattePandaMuCluster.kicad_sch, eth.kicad_sch, hdmi.kicad_sch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]
2025-08-26 Add TVS diodes for ESD protection
    [eth.kicad_sch, hdmi.kicad_sch, mod1.kicad_sch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]
2025-08-28 Fix esd diodes, add some footprints.
    [LattePandaMuCluster.kicad_sch, eth.kicad_sch, hdmi.kicad_sch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]
2025-08-28 Add more footprints
    [eth.kicad_sch, mod1.kicad_sch, mod2.kicad_sch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]
2025-08-29 Add USB Type E Header Footprint
    [eth.kicad_sch, psu.kicad_sch, sata.kicad_sch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]
2025-08-29 Add footprintss from LCSC
    [eth.kicad_sch, sata.kicad_sch, usb.kicad_sch]
2025-08-30 Lots of tiny capacitors
    [eth.kicad_sch, hdmi.kicad_sch, mod1.kicad_sch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]
2025-09-01 Add most passive component footprints
    [eth.kicad_sch, hdmi.kicad_sch, mod1.kicad_sch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]
2025-09-02 Add m.2 slot footprints
    [LattePandaMuCluster.kicad_sch, eth.kicad_sch, hdmi.kicad_sch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]
2025-09-09 Finish fixing footprints
    [LattePandaMuCluster.kicad_sch, eth.kicad_sch, hdmi.kicad_sch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]
2025-09-10 Begin setting up PCB
    [LattePandaMuCluster.kicad_pcb, pcie.kicad_sch]
2025-09-13 Arranging components
    [LattePandaMuCluster.kicad_pcb, eth.kicad_sch]
2025-09-13 reposition nix for better space use (maybe)
    [LattePandaMuCluster.kicad_pcb]
2025-09-13 Move slots down to make more room for top io
    [LattePandaMuCluster.kicad_pcb]
2025-09-14 Fix more footprint issues, continue laying out components
    [LattePandaMuCluster.kicad_pcb, mod1.kicad_sch, mod2.kicad_sch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]
2025-09-14 Place STM32 and fix cpu fan headers
    [LattePandaMuCluster.kicad_pcb, mod1.kicad_sch, mod2.kicad_sch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]
2025-09-14 Place fan headers, adjust other components'
    [LattePandaMuCluster.kicad_pcb]
2025-09-21 Lay out Headers
    [LattePandaMuCluster.kicad_pcb, stm32.kicad_sch]
2025-09-26 Start placing capacitors
    [LattePandaMuCluster.kicad_pcb]
2025-10-27 Add PCIe x1 Slot
    [LattePandaMuCluster.kicad_sch, pcie.kicad_sch]
2025-11-09 Finish connecting x1 slot. Add pcie clkreq lines
    [LattePandaMuCluster.kicad_pcb, LattePandaMuCluster.kicad_sch, hdmi.kicad_sch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]
2025-11-09 Re-annotate schematic
    [LattePandaMuCluster.kicad_pcb, eth.kicad_sch, hdmi.kicad_sch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]
2025-11-09 Connect clkreq to nics, fix pcie x1 footprint
    [LattePandaMuCluster.kicad_pcb, eth.kicad_sch]
2025-11-09 forgot to save schematic
2025-11-24 change sata symbols
    [mod1.kicad_sch, mod3.kicad_sch, pcie.kicad_sch]
2025-11-25 Begin moving IO to module sheets
    [mod1.kicad_sch, nvme.kicad_sch, pcie.kicad_sch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]
2025-11-26 Add Ethernet to module sheet
    [eth.kicad_sch, mod1.kicad_sch]
2025-11-28 Switch back to RTL8125B
    [mod1.kicad_sch]
2025-11-28 Move HDMI to module sheet
    [hdmi.kicad_sch, mod1.kicad_sch]
